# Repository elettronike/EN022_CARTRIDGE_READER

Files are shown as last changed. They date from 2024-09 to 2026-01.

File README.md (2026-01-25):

# EN022 CARTRIDGE READER

## Supported Console Cartridge.

## (GB) Game Boy
[Game Boy related schematics](https://github.com/Gekkio/gb-schematics?tab=readme-ov-file) 

[Jeff Frohwein's GameBoy Tech Page](http://www.devrs.com/gb/files/hardware.html)
Cartridge Voltage 3.3V
System Clock: 4MHz

## (GBA) Gameboy Advanced

[retrosix](https://www.retrosix.wiki/schematics-game-boy-advance) Here are the original scanned schematics of the Game Boy Advance console.

## (NES)

[schematics](https://github.com/schenkzoola/NES)
[nesdev cartridge connector](https://www.nesdev.org/wiki/Cartridge_connector)

Cartridge Voltage 3.3V

## (SNES)

### SNES CIC

## (N64) Nintendo 64

## (MS) Master System

## PCE/TG16	

## Wonderswan	

## CASIO  Loopy

## References

# License

All the schematics in this repository are licensed very liberally under CC BY 4.0, so you can copy, distribute, modify, or even sell them commercially if you want. There's just one requirement: attribution

Basically it just means this: don't remove the original creator's name, or at least somehow acknowledge them. [Here's the full description about it in CC BY 4.0(https://creativecommons.org/licenses/by/4.0/#deed-conditions)]

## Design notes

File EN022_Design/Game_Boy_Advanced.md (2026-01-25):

# Game Boy Advanced

## Pinout

32pin cartridge slot.

The cartridge bus may be used for both CGB and GBA game paks. In GBA mode, it is used as follows:

| Pin | Name | Dir | Description |
| ----- | --- | --- | :--- |
| 1 | VDD35  | ⟸  | Power Supply (3.3VDC/5VDC) |
| 2 | PHI | ⟸  | System Clock (selectable none, 4.19MHz, 8.38MHz, 16.78MHz) |
| 3 | /WR | ⟸  | Write Select |
| 4 | /RD | ⟸  | Read Select |
| 5 | /CS | ⟸  | ROM Chip Select |
| 6-21  | AD0-15 | ⟺  | lower 16bit Address and/or 16bit ROM-data (see below) |
| 22-29 | A16-23 | ⟺  | upper 8bit ROM-Address or 8bit SRAM-data (see below) |
| 30 | /CS2 | ⟸  | SRAM Chip Select |
| 31 | /REQ | ⟹  | Interrupt request (/IREQ) or DMA request (/DREQ) |
| 32 | GND | --  | Ground 0V |

*Note: Direction is cartridge relative Game Boy.*

### GBA Game Pak SRAM

A 16bit address is outputed through AD0-AD15, then 8bit of data are transferred through A16-A23.

### GBA Game Pak ROM

24bit address is output through AD0-AD15 and A16-A23, then 16bit of data are transferred through AD0-AD15. The 24bit address is formed from the actual 25bit memory address (byte-steps), divided by two (halfword-steps).

### Game Pak 8-bit

In 8-bit mode 5V is used. [GBA](http://hardwarebook.info/GBA "GBA") & [GBA SP](http://hardwarebook.info/GBA_SP "GBA SP") have a mechanical switch which the card pushes to select between 3V or 5V.

In 8bit mode, the cartridge bus works much like for GBA SRAM, however, the 8bit /CS signal is expected at Pin 5, while GBA SRAM /CS2 at Pin 30 is interpreted as /RESET signal by the 8bit MBC chip (if any). In practice, this appears to result in 00h being received as data when attempting to read-out 8bit cartridges from inside of GBA mode.

## Compatibility

Compatibility for differents Game Pak type:

| | Original | Dual Mode | Color only | Advanced only |
| --- | --- | --- | --- | --- |
| [Game Boy](http://hardwarebook.info/GB "GB") | OK | OK | - | - |
| Game Boy Pocket | OK | OK | - | - |
| [Game Boy Color](http://hardwarebook.info/GBC "GBC") | OK | OK | OK | - |
| [Game Boy Advance](http://hardwarebook.info/GBA "GBA") / [Game Boy Advance SP](http://hardwarebook.info/GBA_SP "GBA SP") | OK | OK | OK | OK |
| Nintendo[GameCube](http://hardwarebook.info/GameCube "GameCube") Game Boy Player | OK | OK | OK | OK |
| [Game Boy Micro](http://hardwarebook.info/GBM "GBM") | - | - | - | OK |
| [Nintendo DS](http://hardwarebook.info/NDS "NDS") / [Nintendo DS Lite](http://hardwarebook.info/NDSL "NDSL") | - | - | - | OK |

## Game PAK ROM

16-bit with variable size: This is the place where the cartridge ROM is accessed.
While it may provide one of the slowest rates, it’s also mirrored in the memory map to manage different access speeds.
Additionally, Nintendo fitted a Prefetch Buffer that interfaces the cartridge to alleviate excessive stalling.
This component independently caches continuous addresses when the CPU is not accessing the cartridge, it can hold up to eight 16-bit words.
In practice, however, the CPU will rarely let the Prefetch Buffer do its job.
Since by default it will keep fetching instructions from the cartridge to continue execution [20] (hence why IWRAM and EWRAM are so critical).

## Game PAK RAM

8-bit with variable size: This is the place where the cartridge RAM (SRAM or Flash Memory) is accessed.
This is strictly an 8-bit bus (the CPU will see ‘garbage’ in the unused bits) and for this reason, Nintendo states that it can only be operated through their libraries.

## Game pack Detection Switch

## References

[Game Boy Advance Architecture](https://www.copetti.org/writings/consoles/game-boy-advance/)
[Game Pak](http://hardwarebook.info/Game_Pak)
[GBATEK](https://problemkaputt.de/gbatek.htm#gbatechnicaldata) Gameboy Advance / Nintendo DS / DSi / 3DS - Technical Info - Extracted from no$gba version 3.05
[GBxCartRead ](https://www.insidegadgets.com/2016/12/06/gbxcartread-part-1-design-and-testing-gameboy-carts/)– Part 1: Design and Testing Gameboy Carts

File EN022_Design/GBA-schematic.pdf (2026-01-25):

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

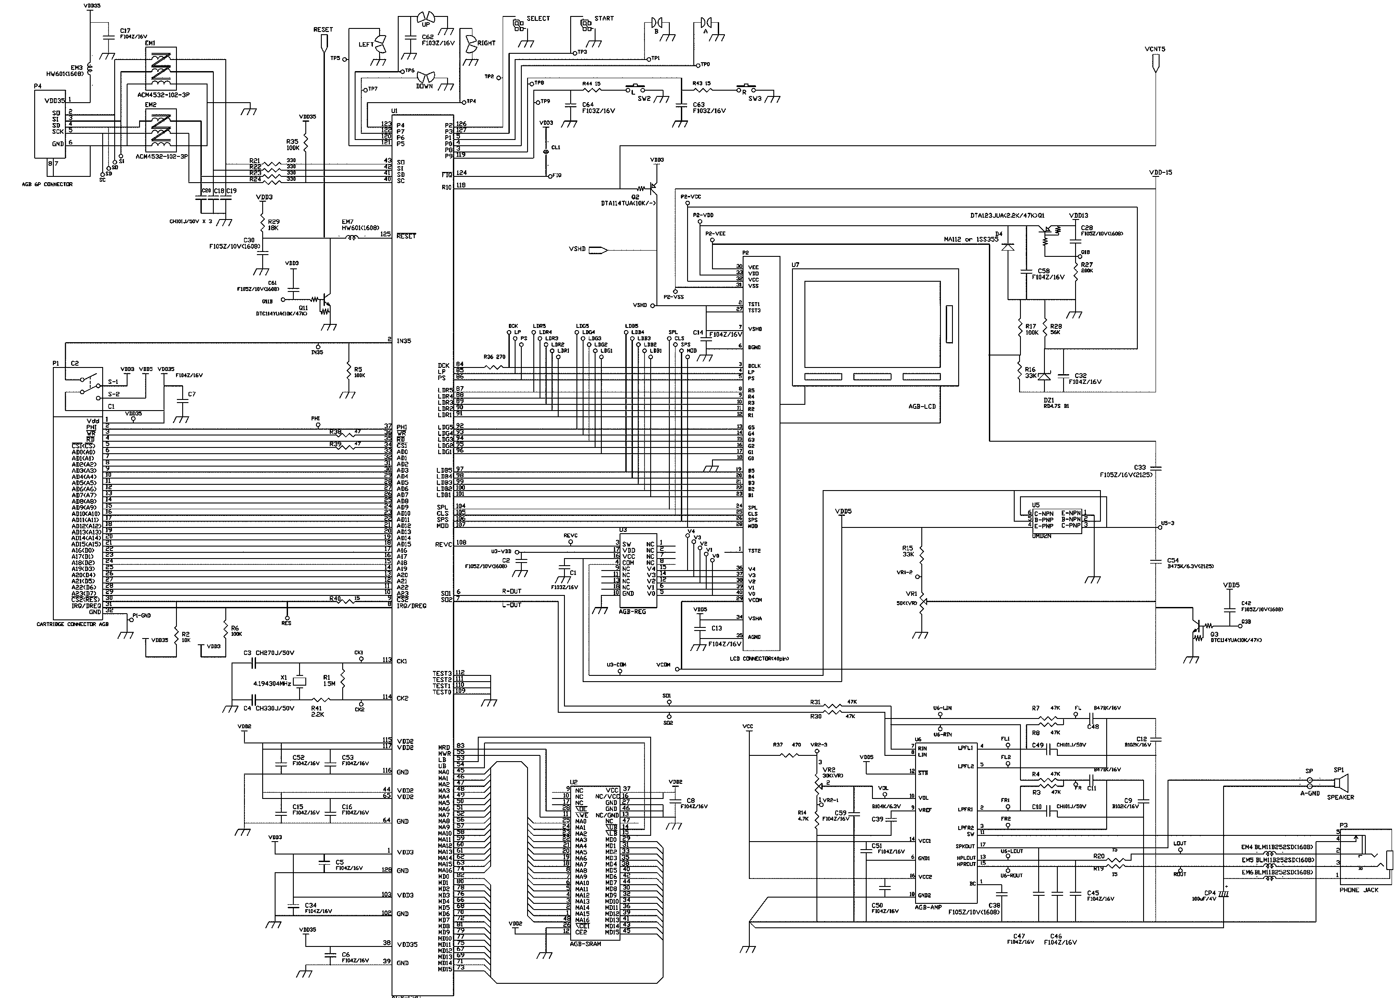
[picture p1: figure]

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

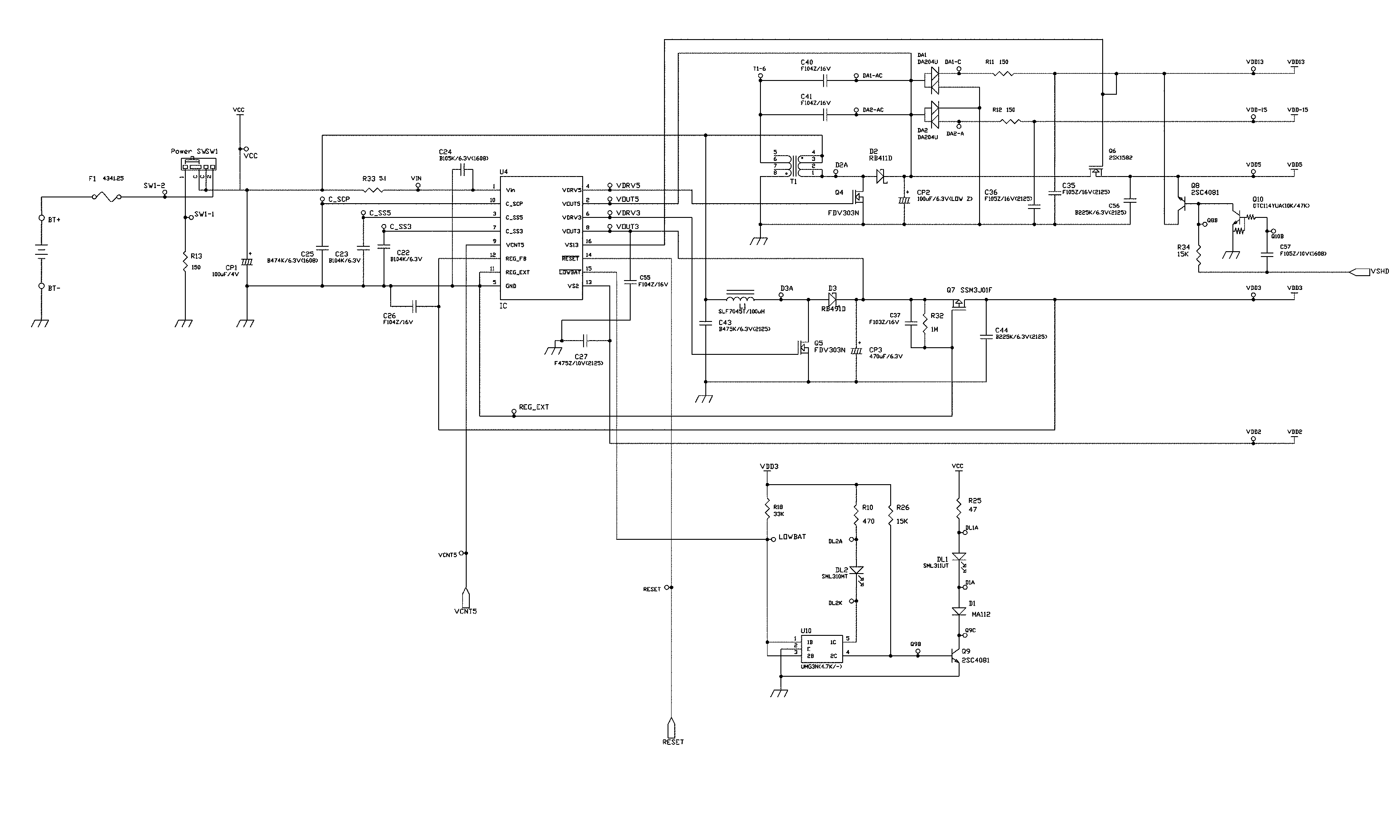
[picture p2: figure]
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

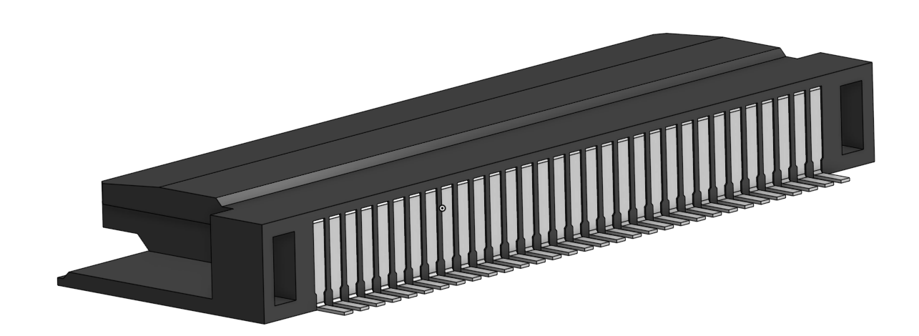
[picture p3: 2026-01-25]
gbcc2.png

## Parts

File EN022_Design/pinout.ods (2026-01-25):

Arduino | Alt. Arduino | ATMega2560 | CH32V307VCT6 | FUNCTION | Game Boy | GBA | NES | SNES | snesCIC | N64 ROM | N64 Controller | N64 EEP | Master System | Megadrive | PCE/TG16 | Wonderswan | CASIO Loopy | LED | SD Card | OLED | LCD | Button | Rotary Encoder | Neopixel | 16bit Flash | 8bit Flash | 16bit Flash in 8bit Mode | 27C322 Eprom
A0 | D54 | PF0 |  |  | A0 | AD0 | M2 | A0 |  | AD0 |  |  | A0 | A1 | A0 | A-1 | D10 |  |  |  |  |  |  |  | A0 | A0 | D15 | A0
A1 | D55 | PF1 |  |  | A1 | AD1 | PRG_CE | A1 |  | AD1 |  |  | A1 | A2 | A1 | A0 | D8 |  |  |  |  |  |  |  | A1 | A1 | A0 | A1
A2 | D56 | PF2 |  |  | A2 | AD2 | CHR_WR | A2 |  | AD2 |  |  | A2 | A3 | A2 | A1 | D6 |  |  |  |  |  |  |  | A2 | A2 | A1 | A2
A3 | D57 | PF3 |  |  | A3 | AD3 | CIRAM_CE | A3 |  | AD3 |  |  | A3 | A4 | A3 | A2 | D4 |  |  |  |  |  |  |  | A3 | A3 | A2 | A3
A4 | D58 | PF4 |  |  | A4 | AD4 | CHR_/A13 | A4 |  | AD4 |  |  | A4 | A5 | A4 | A3 | D14 |  |  |  |  |  |  |  | A4 | A4 | A3 | A4
A5 | D59 | PF5 |  |  | A5 | AD5 | CHR_RD | A5 |  | AD5 |  |  | A5 | A6 | A5 | A4 | D3 |  |  |  |  |  |  |  | A5 | A5 | A4 | A5
A6 | D60 | PF6 |  |  | A6 | AD6 | IRQ | A6 |  | AD6 |  |  | A6 | A7 | A6 | A5 | D2 |  |  |  |  |  |  |  | A6 | A6 | A5 | A6
A7 | D61 | PF7 |  |  | A7 | AD7 | PRG_RW | A7 |  | AD7 |  |  | A7 | A8 | A7 | A6 | RESET |  |  |  |  |  |  |  | A7 | A7 | A6 | A7
A8 | D62 | PK0 |  |  | A8 | AD8 | D0 | A8 |  | AD8 |  |  | A8 | A9 | A8 | A7 | D0 |  |  |  |  |  |  |  | A8 | A8 | A7 | A8
A9 | D63 | PK1 |  |  | A9 | AD9 | D1 | A9 |  | AD9 |  |  | A9 | A10 | A9 | A8 | A0 |  |  |  |  |  |  |  | A9 | A9 | A8 | A9
A10 | D64 | PK2 |  |  | A10 | AD10 | D2 | A10 |  | AD10 |  |  | A10 | A11 | A10 | A9 | A1 |  |  |  |  |  |  |  | A10 | A10 | A9 | A10
A11 | D65 | PK3 |  |  | A11 | AD11 | D3 | A11 |  | AD11 |  |  | A11 | A12 | A11 | A10 | A21 |  |  |  |  |  |  |  | A11 | A11 | A10 | A11
A12 | D66 | PK4 |  |  | A12 | AD12 | D4 | A12 |  | AD12 |  |  | A12 | A13 | A12 | A11 | A3 |  |  |  |  |  |  |  | A12 | A12 | A11 | A12
A13 | D67 | PK5 |  |  | A13 | AD13 | D5 | A13 |  | AD13 |  |  | A13 | A14 | A13 | A12 | A20 |  |  |  |  |  |  |  | A13 | A13 | A12 | A13
A14 | D68 | PK6 |  |  | A14 | AD14 | D6 | A14 |  | AD14 |  |  | A14 | A15 | A14 | A13 | A15 |  |  |  |  |  |  |  | A14 | A14 | A13 | A14
A15 | D69 | PK7 |  |  | A15 | AD15 | D7 | A15 |  | AD15 |  |  |  | A16 | A15 | A14 | A13 |  |  |  |  |  |  |  | A15 | A15 | A14 | A15
D0 | RX0 | PE0
D1 | TX0 | PE1 |  |  |  |  |  |  |  |  |  |  |  |  |  |  |  | build-in (LCD blink)
D2 | PWM | PE4 |  |  |  |  |  | WRAM |  |  |  |  |  | (YS) |  | IO | D11
D3 | PWM | PE5 |  |  |  |  |  | REFRESH |  |  |  |  |  | CAS2 |  | CLK | D9
D4 | PWM | PG5 |  |  |  |  |  | EXPAND |  |  |  |  |  | ASEL |  | Int | D15
D5 | PWM | PE3 |  |  |  |  |  |  |  |  |  |  |  | EDCLK
D6 | PWM | PH3 |  |  | CS | CS_ROM |  | CS |  |  |  |  | A15/M0-7 | CS | OE | CART | RAMWE |  |  |  |  |  |  |  | BYTE | OE | OE
D7 (1K Pullup) | PWM | PH4 |  |  | Sound | IRQ |  | IRQ |  |  | DATA | DATA |  | WR HIGH | IRQ2 | MMC | RAMCS2 |  |  |  |  |  |  |  | WE
D8 | PWM | PH5 |  |  | WR | WR |  | WR |  | WR |  |  | WR | WR LOW | WR | WE |  |  |  |  |  |  |  |  | WP | WE | WE | To NPN transistor controlling VPP 12V stepup regulator module
D9 | PWM | PH6 |  |  | RD | RD |  | RD |  | RD |  |  | OE | OE |  | OE |  |  |  |  |  |  |  |  | CE | CE | CE | CE
D10 | PWM | PB4 |  |  |  |  |  |  |  |  |  |  |  |  |  |  |  | Blue (OLED blink) |  |  | Reset
D11 | PWM | PB5 |  |  |  |  |  |  |  |  |  |  |  |  |  |  |  | Green |  |  | DC/A0
D12 | PWM | PB6 |  |  |  |  |  |  |  |  |  |  |  |  |  |  |  | Red |  |  | CS
D13 | PWM | PB7 |  |  |  |  |  |  |  |  |  |  |  |  |  |  |  | build-in (Serial blink) |  |  |  |  |  | Neopixel
D14 | TX3 | PJ1 |  |  |  |  |  | PAWR |  |  |  |  |  | AS |  |  | D12
D15 | RX3 | PJ0 |  |  |  |  |  | PARD |  |  |  |  |  | Time |  |  | D13
D16 | TX2 | PH1 |  | CLOCK | CLK | CLK |  |  |  |  |  |  | CLK | VCLK
D17 | RX2 | PH0 |  | RESET | Reset | CS_RAM |  | Reset |  | Reset |  | Reset | Reset | (MRES),VRES | RST | Reset |  |  |  |  |  |  |  |  | Reset | Reset | Reset
D18 | TX1 | PD3 |  |  |  |  |  |  |  |  |  |  |  |  |  |  |  |  |  |  |  |  | ENC1
D19 | RX1 | PD2 |  |  |  |  |  |  |  |  |  |  |  |  |  |  |  |  |  |  |  |  | ENC2
D20 | SDA | PD1 |  |  |  |  |  |  |  |  |  |  |  |  |  |  |  |  |  | SDA
D21 | SCL | PD0 |  |  |  |  |  |  |  |  |  |  |  |  |  |  |  |  |  | SCL
D22 |  | PA0 |  |  |  |  | A8 | PA0 |  |  |  |  |  | D8 |  | D8 | D1 |  |  |  |  |  |  |  | D8 |  |  | D8
D23 |  | PA1 |  |  |  |  | A9 | PA1 |  |  |  |  |  | D9 |  | D9 | A2 |  |  |  |  |  |  |  | D9 |  |  | D9
D24 |  | PA2 |  |  |  |  | A10 | PA2 |  |  |  |  |  | D10 |  | D10 | A4 |  |  |  |  |  |  |  | D10 |  |  | D10
D25 |  | PA3 |  |  |  |  | A11 | PA3 |  |  |  |  |  | D11 |  | D11 | A19 |  |  |  |  |  |  |  | D11 |  |  | D11
D26 |  | PA4 |  |  |  |  | A12 | PA4 |  |  |  |  |  | D12 |  | D12 | A18 |  |  |  |  |  |  |  | D12 |  |  | D12
D27 |  | PA5 |  |  |  |  | A13 | PA5 |  |  |  |  |  | D13 |  | D13 | A16 |  |  |  |  |  |  |  | D13 |  |  | D13
D28 |  | PA6 |  |  |  |  | A14 | PA6 |  |  |  |  |  | D14 |  | D14 | A17 |  |  |  |  |  |  |  | D14 |  |  | D14
D29 |  | PA7 |  |  |  |  |  | PA7 |  |  |  |  |  | D15 |  | D15 | A14 |  |  |  |  |  |  |  | D15 |  |  | D15
D30 |  | PC7 |  |  | D7 | A23 |  | D7 |  |  |  |  | D7 | D7 | D7 | D7 |  |  |  |  |  |  |  |  | D7 | D7 | D7 | D7
D31 |  | PC6 |  |  | D6 | A22 |  | D6 |  |  |  |  | D6 | D6 | D6 | D6 |  |  |  |  |  |  |  |  | D6 | D6 | D6 | D6
D32 |  | PC5 |  |  | D5 | A21 |  | D5 |  |  |  |  | D5 | D5 | D5 | D5 |  |  |  |  |  |  |  |  | D5 | D5 | D5 | D5
D33 |  | PC4 |  |  | D4 | A20 |  | D4 |  |  |  |  | D4 | D4 | D4 | D4 |  |  |  |  |  |  |  |  | D4 | D4 | D4 | D4
D34 |  | PC3 |  |  | D3 | A19 |  | D3 |  |  |  |  | D3 | D3 | D3 | D3 | A12 |  |  |  |  |  |  |  | D3 | D3 | D3 | D3
D35 |  | PC2 |  |  | D2 | A18 | CIRAM_A10 | D2 |  |  |  |  | D2 | D2 | D2 | D2 | A10 |  |  |  |  |  |  |  | D2 | D2 | D2 | D2
D36 |  | PC1 |  |  | D1 | A17 |  | D1 |  | ALE_H |  |  | D1 | D1 | D1 | D1 | A8 |  |  |  |  |  |  |  | D1 | D1 | D1 | D1
D37 |  | PC0 |  |  | D0 | A16 |  | D0 |  | ALE_L |  |  | D0 | D0 | D0 | D0 | A6 |  |  |  |  |  |  |  | D0 | D0 | D0 | D0
D38 |  | PD7 |  |  |  |  |  |  |  |  |  |  |  |  |  |  |  | HW5 status LED |  |  |  | Button1 (10K Pullup)
D39 |  | PG2 |  |  |  |  |  |  |  |  |  |  |  |  |  |  |  |  |  |  |  | Button 2 (10K Pullup) | ENC Button
D40 |  | PG1 |  |  |  |  |  |  | Reset In (Pin 4) |  |  |  |  |  |  |  | D5
D41 |  | PG0 |  |  |  |  |  |  | Reset Out Host (Pin 3) |  |  |  |  |  |  |  | D7
D42 |  | PL7 |  |  |  |  | A7 | A23 |  |  |  |  |  |  | Card Detect |  | CE
D43 |  | PL6 |  |  |  |  | A6 | A22 |  |  |  |  |  | A23 | Audio In |  | OE |  |  |  |  |  |  |  |  |  | A21
D44 | PWM | PL5 |  |  |  |  | A5 | A21 |  |  |  |  |  | A22 | HSM |  |  |  |  |  |  |  |  |  | A21 | A21 | A20
D45 | PWM | PL4 |  |  |  |  | A4 | A20 |  |  |  |  |  | A21 | CE |  |  |  |  |  |  |  |  |  | A20 | A20 | A19 | A20
D46 | PWM | PL3 |  |  |  |  | A3 | A19 |  |  |  |  |  | A20 | A19 | A18 | A11 |  |  |  |  |  |  |  | A19 | A19 | A18 | A19
D47 |  | PL2 |  |  |  |  | A2 | A18 |  |  |  |  |  | A19 | A18 | A17 | A9 |  |  |  |  |  |  |  | A18 | A18 | A17 | A18
D48 |  | PL1 |  |  |  |  | A1 | A17 |  |  |  |  | CE | A18 | A17 | A16 | A7 |  |  |  |  |  |  |  | A17 | A17 | A16 | A17
D49 |  | PL0 |  |  |  |  | A0 | A16 |  |  |  |  |  | A17 | A16 | A15 | A5 |  |  |  |  |  |  |  | A16 | A16 | A15 | A16
D50 | MISO | PB3 |  | MISO |  |  |  |  |  |  |  |  |  |  |  |  |  |  | MISO
D51 | MOSI | PB2 |  | MOSI |  |  |  |  |  |  |  |  |  |  |  |  |  |  | MOSI |  | MOSI
D52 | SCK | PB1 |  | SCK |  |  |  |  |  |  |  |  |  |  |  |  |  |  | SCK |  | SCK
D53 | SS | PB0 |  | SS |  |  |  |  |  |  |  |  |  |  |  |  |  |  | SS
CLK0 |  |  |  |  |  |  |  | CLK
CLK1 |  |  |  |  |  |  |  | CPUCLK |  |  |  | EEP CLK
CLK2 |  |  |  |  |  |  |  | CICCLK | CLK (Pin 2)
 |  |  |  |  |  |  |  | Reset In | Reset Out Slave (Pin 5)
 |  |  |  |  |  |  |  | CIC1 | CIC1 (Pin 6)
 |  |  |  |  |  |  |  | CIC0 | CIC0 (Pin 7)
GND |  |  |  |  |  |  |  |  |  |  |  |  |  |  |  |  |  |  |  |  |  |  |  |  |  |  | BYTE

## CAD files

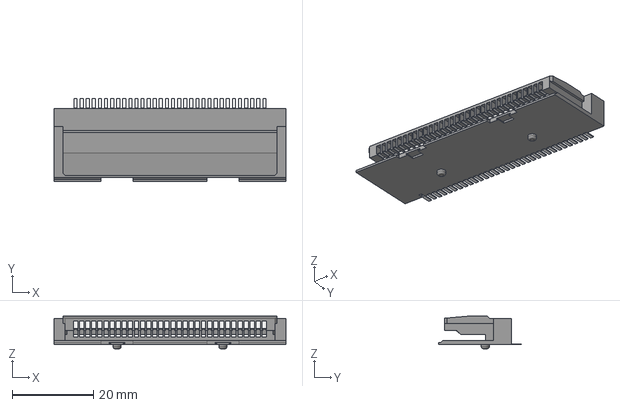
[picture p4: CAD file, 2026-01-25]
footprints/GBA_CartConnector.step
57.0 x 20.4 x 8.00 mm
Pin x 32
Cart_Connector

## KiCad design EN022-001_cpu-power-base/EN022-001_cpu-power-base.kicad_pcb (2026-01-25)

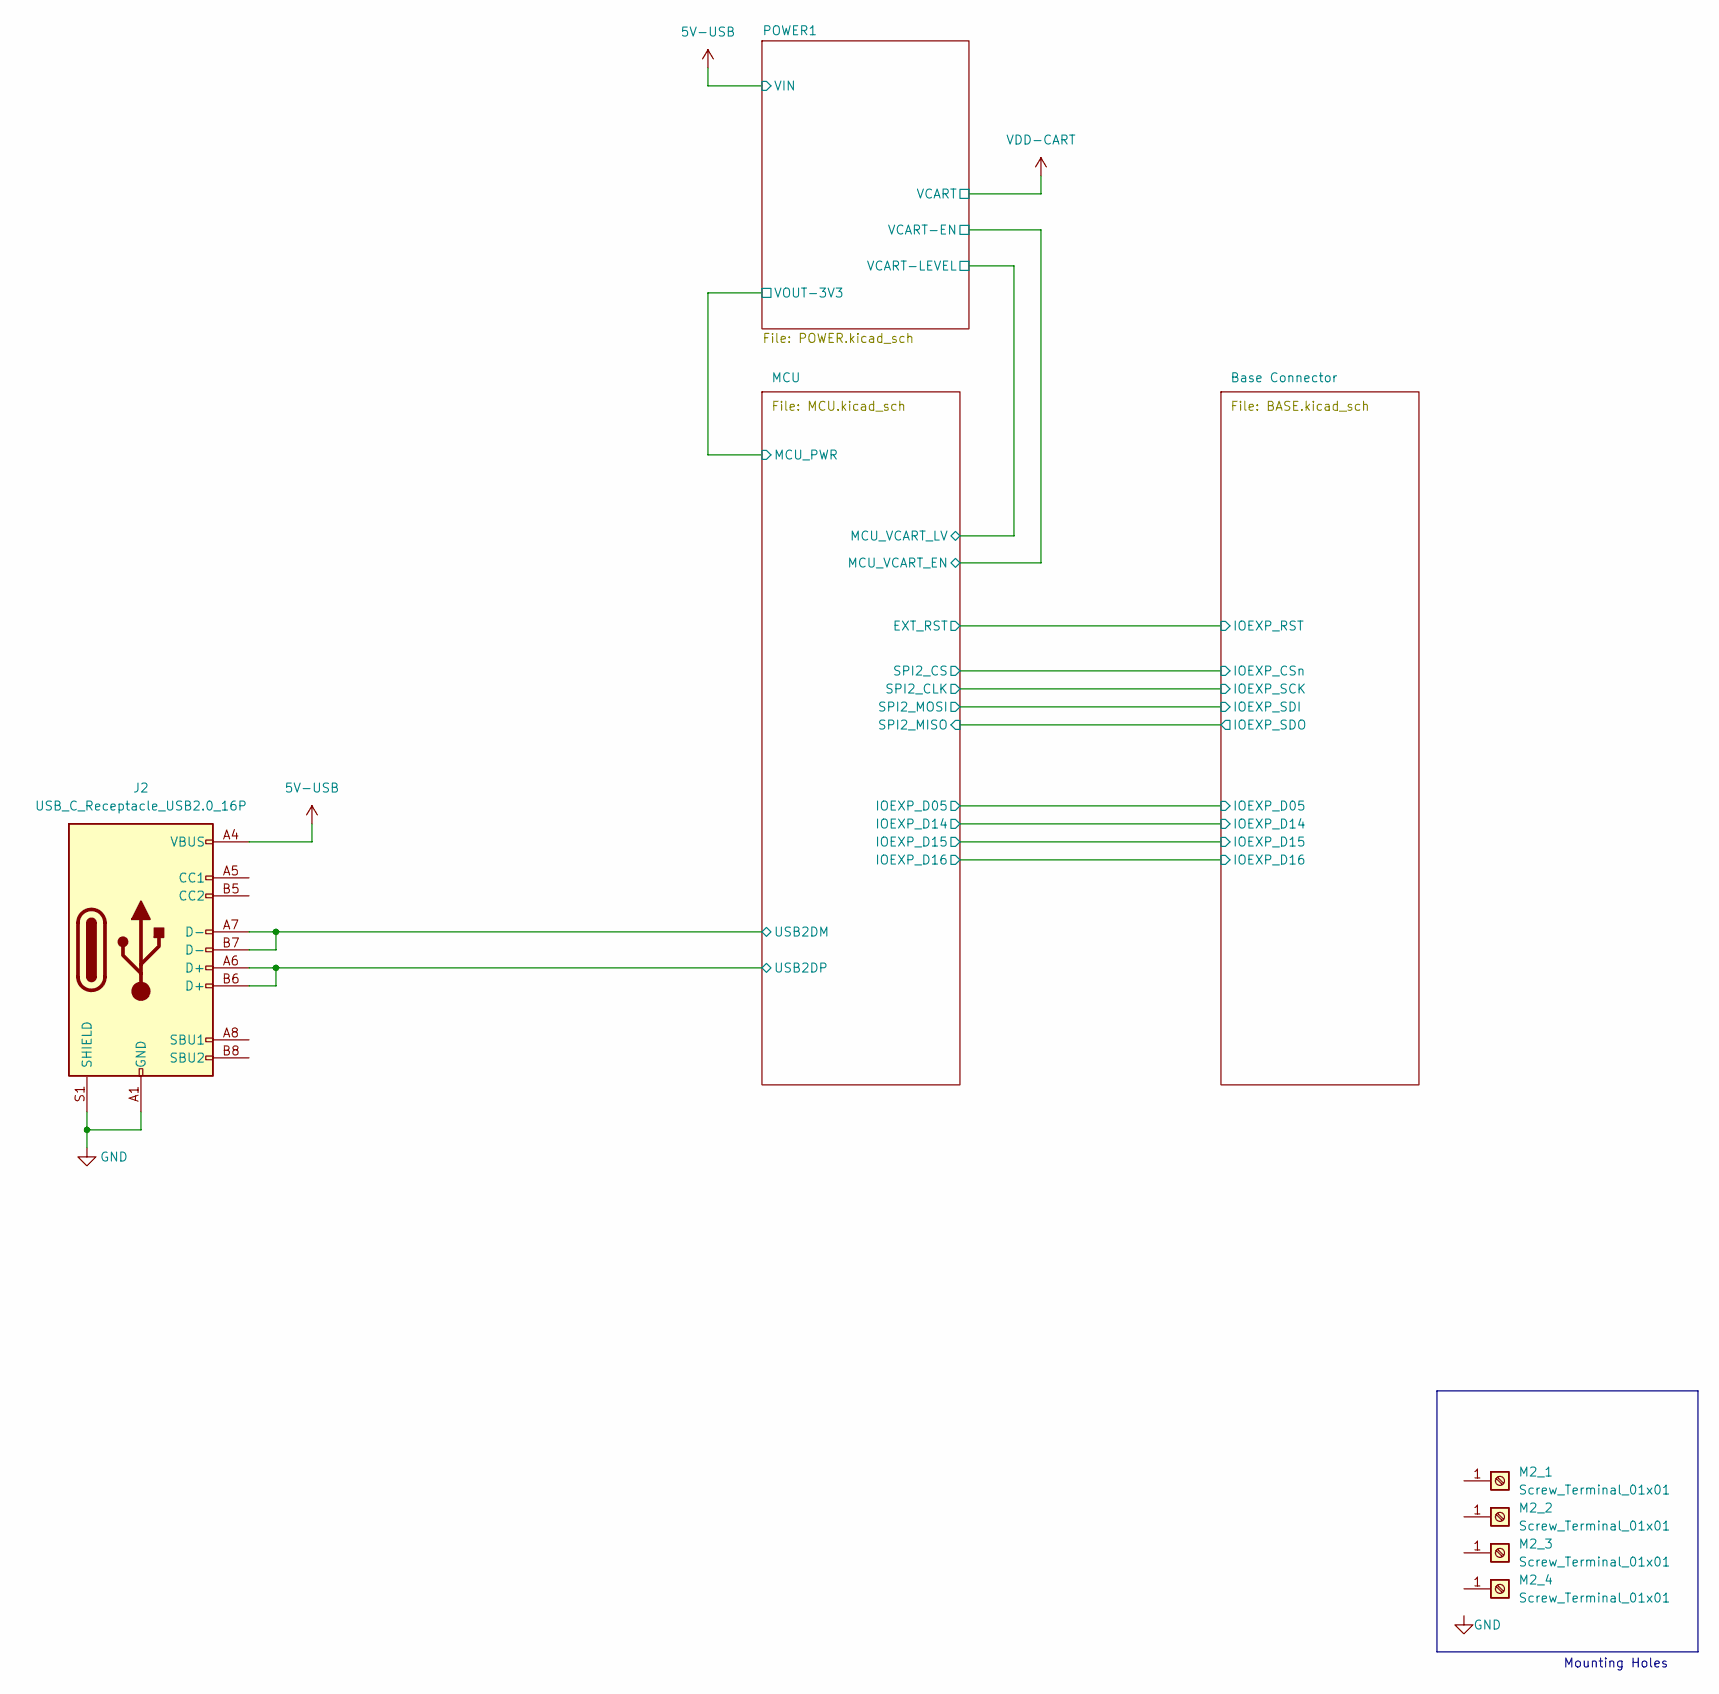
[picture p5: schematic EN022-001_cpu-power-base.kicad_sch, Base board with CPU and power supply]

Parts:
J2: USB_C_Receptacle_USB2.0_16P; USB_C_Receptacle_GCT_USB4105-xx-A_16P_TopMnt_Horizontal
M2_1, M2_2, M2_3, M2_4: Screw_Terminal_01x01

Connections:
5V-USB: J2.A4 (VBUS), J2.A9 (VBUS), J2.B4 (VBUS), J2.B9 (VBUS); also elsewhere on the board
/MCU/USB2DM: J2.A7 (D-), J2.B7 (D-); also elsewhere on the board
/MCU/USB2DP: J2.A6 (D+), J2.B6 (D+); also elsewhere on the board
GND: J2.A1 (GND), J2.A12 (GND), J2.B1 (GND), J2.B12 (GND), J2.S1 (SHIELD); also elsewhere on the board

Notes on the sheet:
Mounting Holes

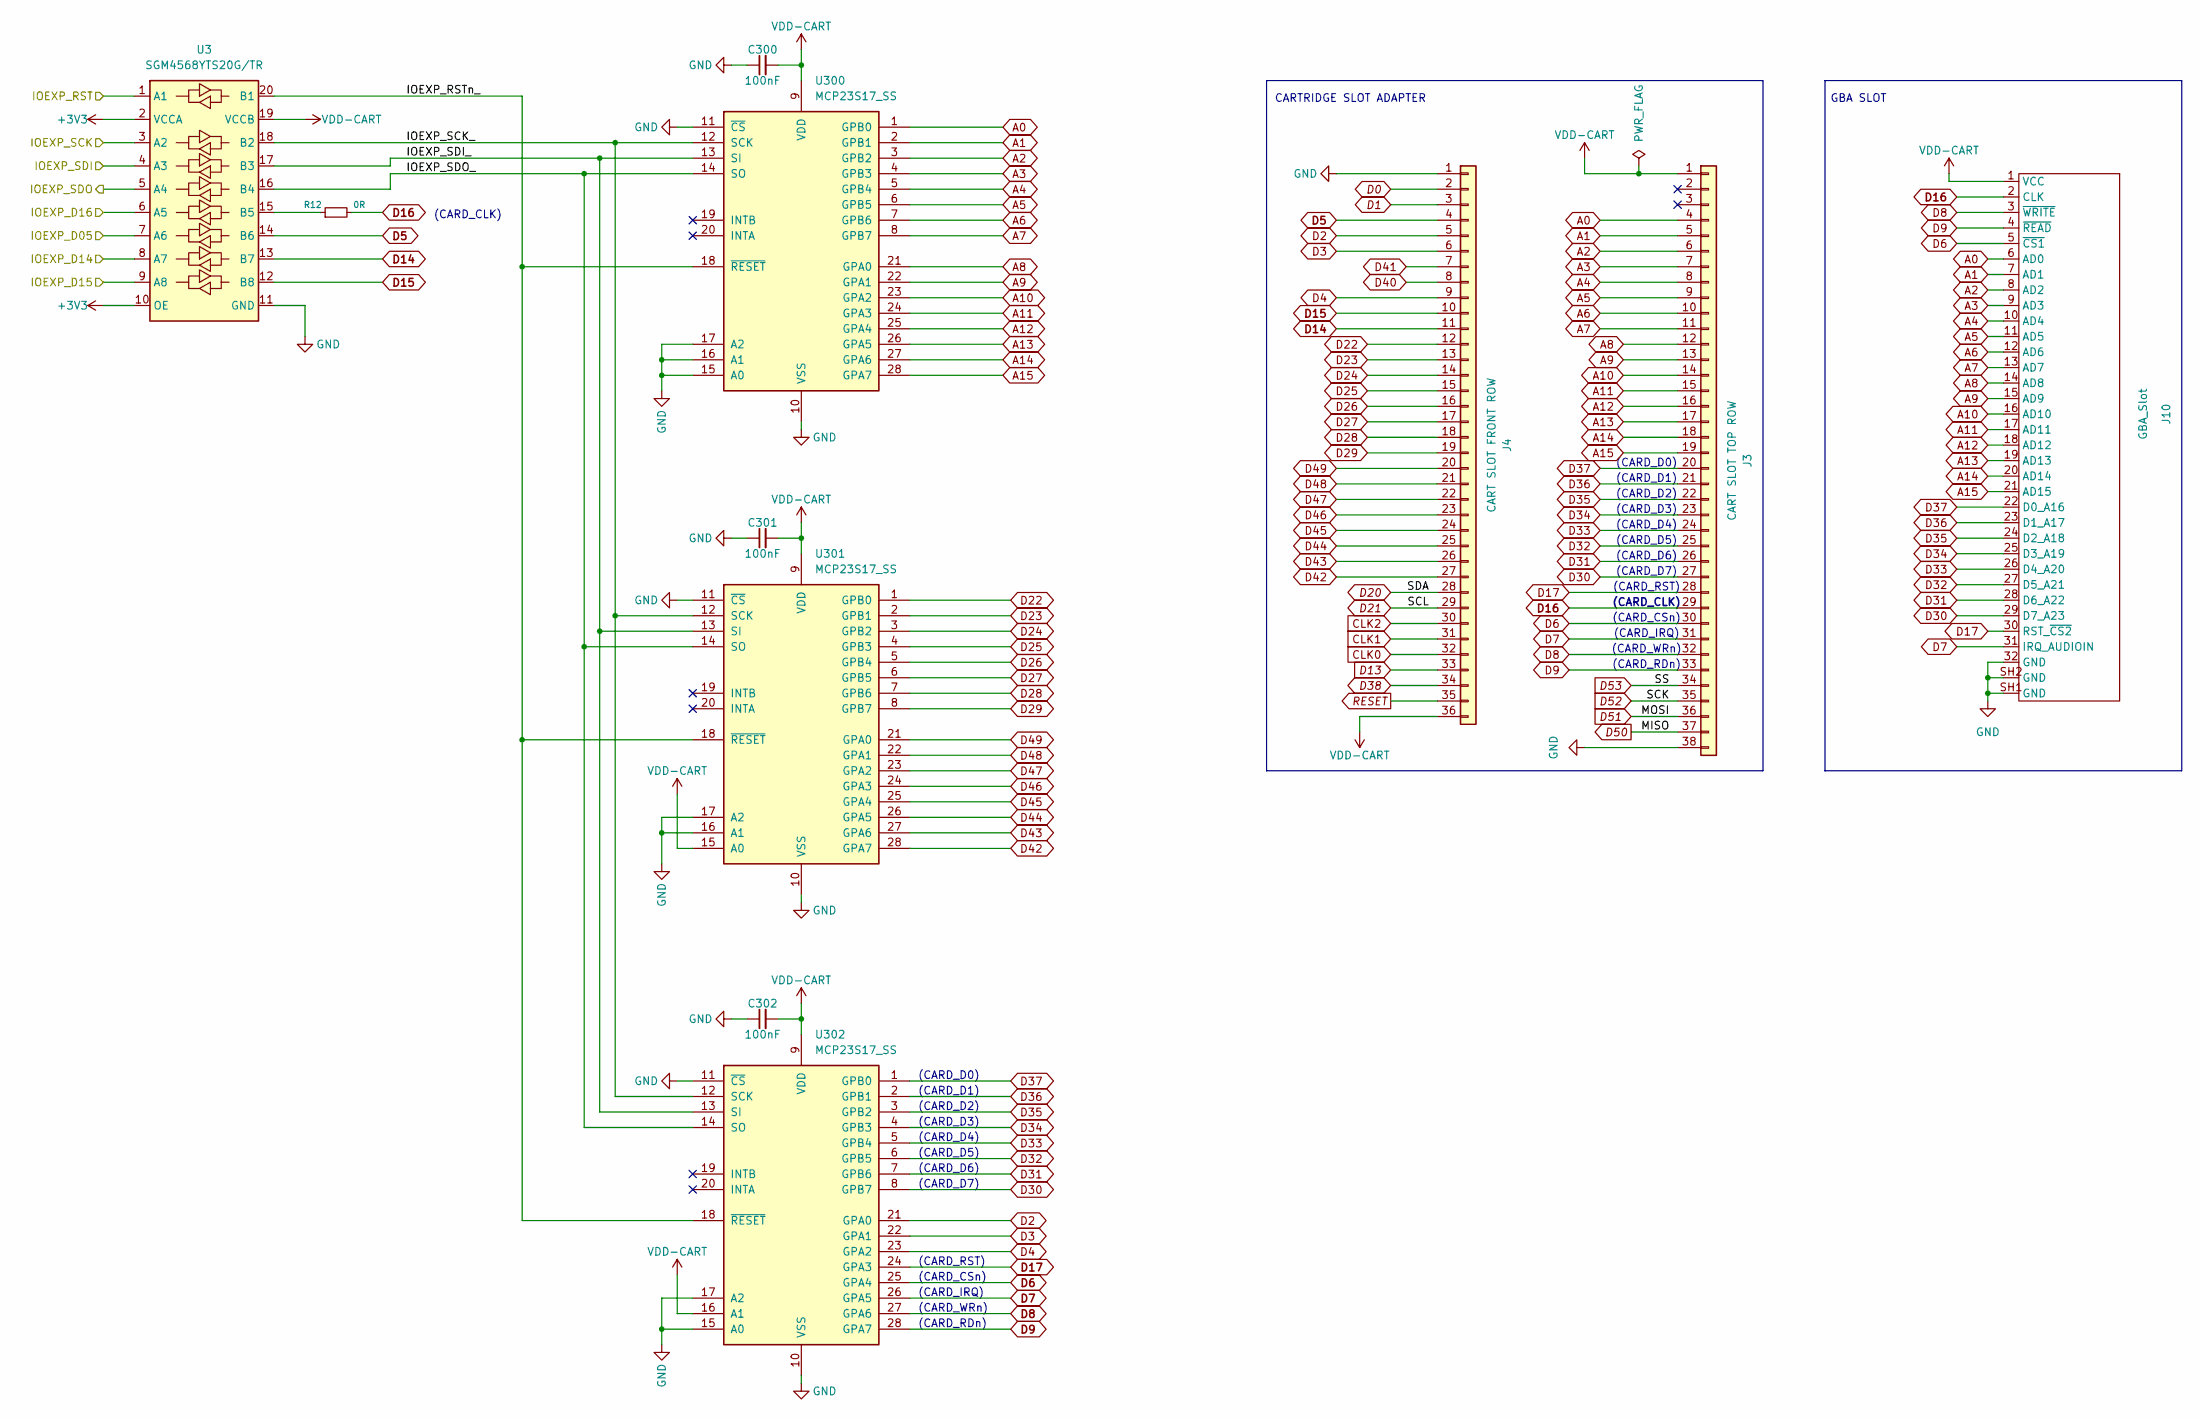
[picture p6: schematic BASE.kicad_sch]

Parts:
C300, C301, C302: 100nF; C_0805_2012Metric_Pad1.18x1.45mm_HandSolder
J3: CART SLOT TOP ROW; Cartridge_Port_Adapter-Back
J4: CART SLOT FRONT ROW; Cartridge_Port_Adapter-Front
J10: GBA_Slot
R12: 0R; R_0805_2012Metric_Pad1.20x1.40mm_HandSolder
U3: SGM4568YTS20G/TR; TSSOP-20_4.4x6.5mm_P0.65mm
U300, U301, U302: MCP23S17_SS; SSOP-28_5.3x10.2mm_P0.65mm

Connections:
+3V3: U3.2 (VCCA), U3.10 (OE); also elsewhere on the board
/Base Connector/IOEXP_D05: U3.7 (A6); also elsewhere on the board
/Base Connector/IOEXP_D14: U3.8 (A7); also elsewhere on the board
/Base Connector/IOEXP_D15: U3.9 (A8); also elsewhere on the board
/Base Connector/IOEXP_D16: U3.6 (A5); also elsewhere on the board
/Base Connector/IOEXP_RST: U3.1 (A1); also elsewhere on the board
/Base Connector/IOEXP_RSTn_: U3.20 (B1), U300.18 (~RESET), U301.18 (~RESET), U302.18 (~RESET)
/Base Connector/IOEXP_SCK: U3.3 (A2); also elsewhere on the board
/Base Connector/IOEXP_SCK_: U3.18 (B2), U300.12 (SCK), U301.12 (SCK), U302.12 (SCK)
/Base Connector/IOEXP_SDI: U3.4 (A3); also elsewhere on the board
/Base Connector/IOEXP_SDI_: U3.17 (B3), U300.13 (SI), U301.13 (SI), U302.13 (SI)
/Base Connector/IOEXP_SDO: U3.5 (A4); also elsewhere on the board
/Base Connector/IOEXP_SDO_: U3.16 (B4), U300.14 (SO), U301.14 (SO), U302.14 (SO)
A0: J3.4, J10.6 (AD0), U300.1 (GPB0)
A1: J3.5, J10.7 (AD1), U300.2 (GPB1)
A2: J3.6, J10.8 (AD2), U300.3 (GPB2)
A3: J3.7, J10.9 (AD3), U300.4 (GPB3)
A4: J3.8, J10.10 (AD4), U300.5 (GPB4)
A5: J3.9, J10.11 (AD5), U300.6 (GPB5)
A6: J3.10, J10.12 (AD6), U300.7 (GPB6)
A7: J3.11, J10.13 (AD7), U300.8 (GPB7)
A8: J3.12, J10.14 (AD8), U300.21 (GPA0)
A9: J3.13, J10.15 (AD9), U300.22 (GPA1)
A10: J3.14, J10.16 (AD10), U300.23 (GPA2)
A11: J3.15, J10.17 (AD11), U300.24 (GPA3)
A12: J3.16, J10.18 (AD12), U300.25 (GPA4)
A13: J3.17, J10.19 (AD13), U300.26 (GPA5)
A14: J3.18, J10.20 (AD14), U300.27 (GPA6)
A15: J3.19, J10.21 (AD15), U300.28 (GPA7)
CLK0: J4.32
CLK1: J4.31
CLK2: J4.30
D0: J4.2
D1: J4.3
D2: J4.5, U302.21 (GPA0)
D3: J4.6, U302.22 (GPA1)
D4: J4.9, U302.23 (GPA2)
D5: J4.4, U3.14 (B6)
D6: J3.30, J10.5 (~CS1), U302.25 (GPA4)
D7: J3.31, J10.31 (IRQ_AUDIOIN), U302.26 (GPA5)
D8: J3.32, J10.3 (~WRITE), U302.27 (GPA6)
D9: J3.33, J10.4 (~READ), U302.28 (GPA7)
D13: J4.33
D14: J4.11, U3.13 (B7)
D15: J4.10, U3.12 (B8)
D16: J3.29, J10.2 (CLK), R12.2
D17: J3.28, J10.30 (RST_~CS2), U302.24 (GPA3)
D20: J4.28
D21: J4.29
D22: J4.12, U301.1 (GPB0)
D23: J4.13, U301.2 (GPB1)
D24: J4.14, U301.3 (GPB2)
D25: J4.15, U301.4 (GPB3)
D26: J4.16, U301.5 (GPB4)
D27: J4.17, U301.6 (GPB5)
D28: J4.18, U301.7 (GPB6)
D29: J4.19, U301.8 (GPB7)
D30: J3.27, J10.29 (D7_A23), U302.8 (GPB7)
D31: J3.26, J10.28 (D6_A22), U302.7 (GPB6)
D32: J3.25, J10.27 (D5_A21), U302.6 (GPB5)
D33: J3.24, J10.26 (D4_A20), U302.5 (GPB4)
D34: J3.23, J10.25 (D3_A19), U302.4 (GPB3)
D35: J3.22, J10.24 (D2_A18), U302.3 (GPB2)
D36: J3.21, J10.23 (D1_A17), U302.2 (GPB1)
D37: J3.20, J10.22 (D0_A16), U302.1 (GPB0)
D38: J4.34
D40: J4.8
D41: J4.7
D42: J4.27, U301.28 (GPA7)
D43: J4.26, U301.27 (GPA6)
D44: J4.25, U301.26 (GPA5)
D45: J4.24, U301.25 (GPA4)
D46: J4.23, U301.24 (GPA3)
D47: J4.22, U301.23 (GPA2)
D48: J4.21, U301.22 (GPA1)
D49: J4.20, U301.21 (GPA0)
D50: J3.37
D51: J3.36
D52: J3.35
D53: J3.34
GND: C300.1, C301.1, C302.1, J3.38, J4.1, J10.32 (GND), J10.SH1 (GND), J10.SH2 (GND), U3.11 (GND), U300.10 (VSS), U300.11 (~CS), U300.15 (A0), U300.16 (A1), U300.17 (A2), U301.10 (VSS), U301.11 (~CS), U301.16 (A1), U301.17 (A2), U302.10 (VSS), U302.11 (~CS), U302.15 (A0), U302.17 (A2); also elsewhere on the board
unnamed: R12.1, U3.15 (B5)
RESET: J4.35
VDD-CART: C300.2, C301.2, C302.2, J3.1, J4.36, J10.1 (VCC), U3.19 (VCCB), U300.9 (VDD), U301.9 (VDD), U301.15 (A0), U302.9 (VDD), U302.16 (A1); also elsewhere on the board

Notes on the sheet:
(CARD_D7)
(CARD_D0)
(CARD_CLK)
(CARD_D6)
GBA SLOT
(CARD_D5)
(CARD_D3)
(CARD_WRn)
(CARD_CSn)
(CARD_D1)
CARTRIDGE SLOT ADAPTER
(CARD_D2)
(CARD_IRQ)
(CARD_D4)
(CARD_RDn)
(CARD_RST)

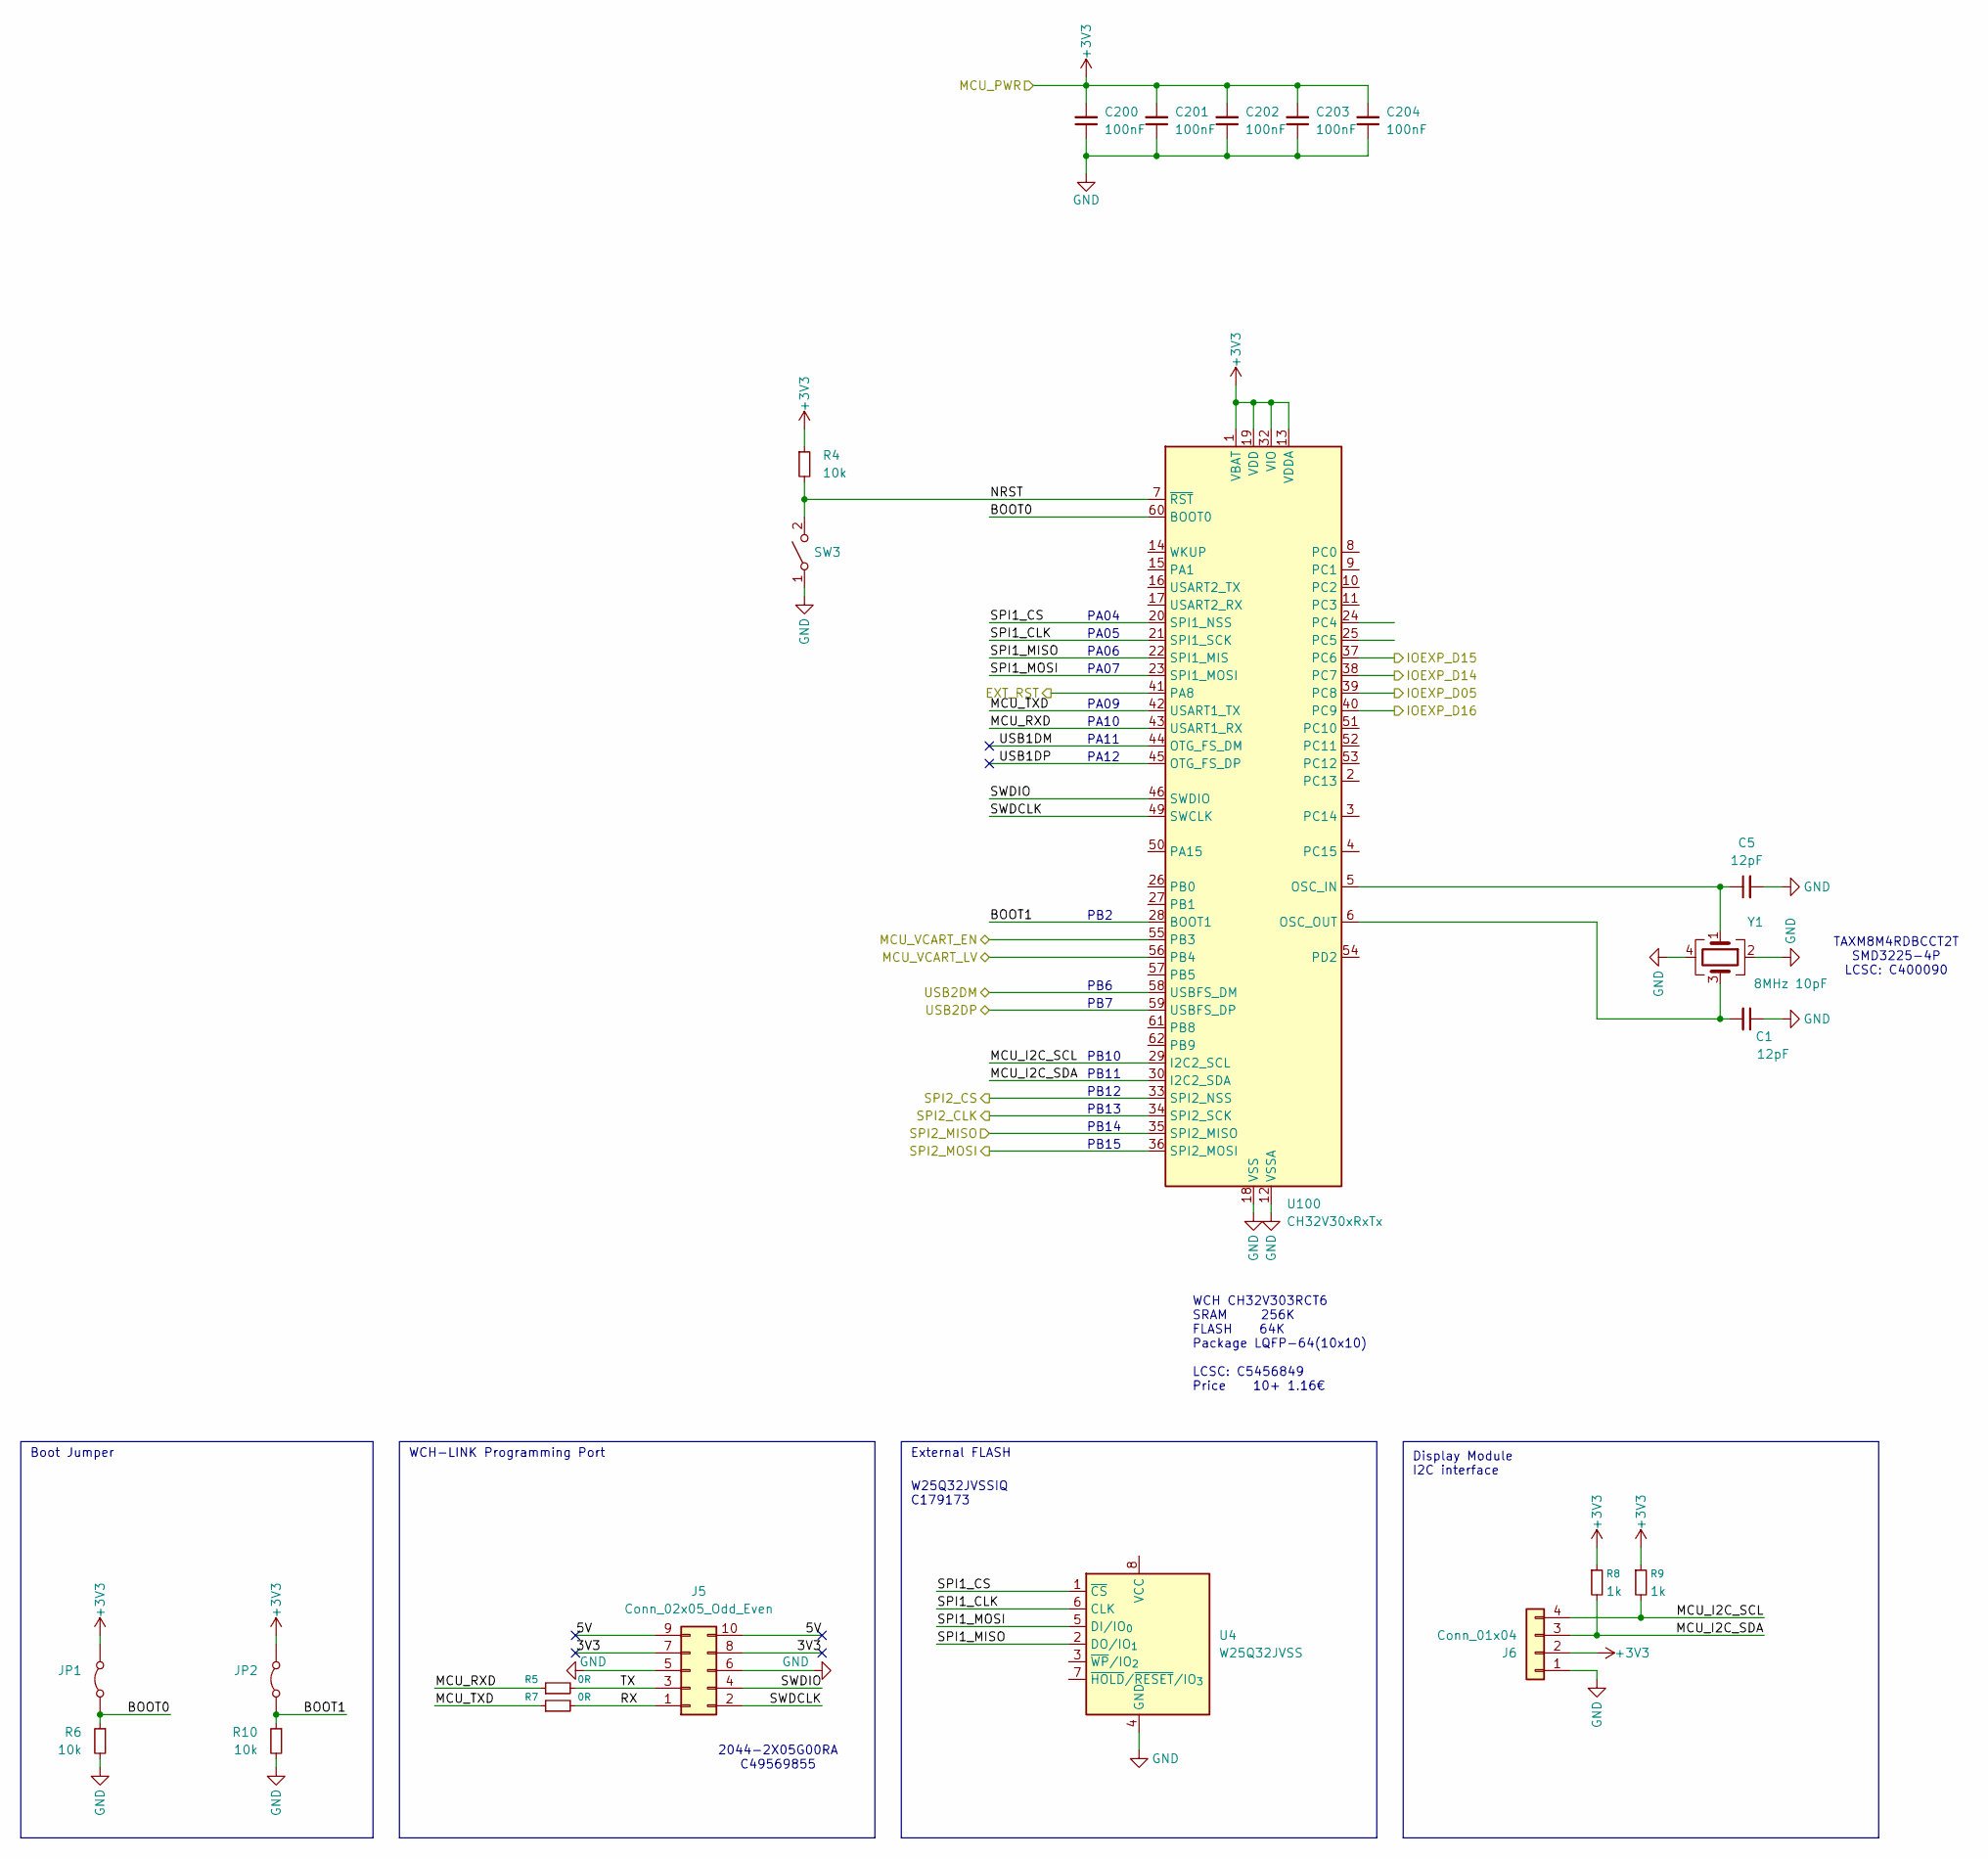
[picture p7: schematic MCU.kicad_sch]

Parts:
C1, C5: 12pF; C_0603_1608Metric_Pad1.08x0.95mm_HandSolder
C200, C201, C202, C203, C204: 100nF; C_0805_2012Metric_Pad1.18x1.45mm_HandSolder
J5: Conn_02x05_Odd_Even; PinSocket_2x05_P2.54mm_Horizontal
J6: Conn_01x04; PinHeader_1x04_P2.54mm_Vertical
JP1, JP2: Jumper_2_Bridged; PinHeader_1x02_P2.54mm_Vertical
R4, R6, R10: 10k; R_0805_2012Metric_Pad1.20x1.40mm_HandSolder
R5, R7: 0R; R_0805_2012Metric_Pad1.20x1.40mm_HandSolder
R8, R9: 1k; R_0805_2012Metric_Pad1.20x1.40mm_HandSolder
SW3: TC-6615-7-260G; SW_Tactile_SPST_Angled_PTS645Vx58-2LFS
U4: W25Q32JVSS; SOIC-8_5.3x5.3mm_P1.27mm
U100: CH32V30xRxTx; LQFP-64_10x10mm_P0.5mm
Y1: 8MHz 10pF; Crystal_SMD_3225-4Pin_3.2x2.5mm_HandSoldering

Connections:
+3V3: C200.2, C201.2, C202.2, C203.2, C204.2, J6.2, JP1.1 (A), JP2.1 (A), R4.1, R8.1, R9.1, U100.1 (VBAT), U100.13 (VDDA), U100.19 (VDD), U100.32 (VIO), U100.48 (VDD), U100.64 (VIO); also elsewhere on the board
/Base Connector/IOEXP_D05: U100.39 (PC8); also elsewhere on the board
/Base Connector/IOEXP_D14: U100.38 (PC7); also elsewhere on the board
/Base Connector/IOEXP_D15: U100.37 (PC6); also elsewhere on the board
/Base Connector/IOEXP_D16: U100.40 (PC9); also elsewhere on the board
/Base Connector/IOEXP_RST: U100.41 (PA8); also elsewhere on the board
/Base Connector/IOEXP_SCK: U100.34 (SPI2_SCK); also elsewhere on the board
/Base Connector/IOEXP_SDI: U100.36 (SPI2_MOSI); also elsewhere on the board
/Base Connector/IOEXP_SDO: U100.35 (SPI2_MISO); also elsewhere on the board
/MCU/3V3: J5.7, J5.8
/MCU/5V: J5.9, J5.10
/MCU/BOOT0: JP1.2 (B), R6.1, U100.60 (BOOT0)
/MCU/BOOT1: JP2.2 (B), R10.1, U100.28 (BOOT1)
/MCU/MCU_I2C_SCL: J6.4, R9.2, U100.29 (I2C2_SCL)
/MCU/MCU_I2C_SDA: J6.3, R8.2, U100.30 (I2C2_SDA)
/MCU/MCU_RXD: R5.1, U100.43 (USART1_RX)
/MCU/MCU_TXD: R7.1, U100.42 (USART1_TX)
/MCU/MCU_VCART_EN: U100.55 (PB3); also elsewhere on the board
/MCU/MCU_VCART_LV: U100.56 (PB4); also elsewhere on the board
/MCU/NRST: R4.2, SW3.2 (B), U100.7 (~RST)
/MCU/RX: J5.1, R7.2
/MCU/SPI1_CLK: U4.6 (CLK), U100.21 (SPI1_SCK)
/MCU/SPI1_CS: U4.1 (~CS), U100.20 (SPI1_NSS)
/MCU/SPI1_MISO: U4.2 (DO/IO_{1}), U100.22 (SPI1_MIS)
/MCU/SPI1_MOSI: U4.5 (DI/IO_{0}), U100.23 (SPI1_MOSI)
/MCU/SPI2_CS: U100.33 (SPI2_NSS)
/MCU/SWDCLK: J5.2, U100.49 (SWCLK)
/MCU/SWDIO: J5.4, U100.46 (SWDIO)
/MCU/TX: J5.3, R5.2
/MCU/USB1DM: U100.44 (OTG_FS_DM)
/MCU/USB1DP: U100.45 (OTG_FS_DP)
/MCU/USB2DM: U100.58 (USBFS_DM); also elsewhere on the board
/MCU/USB2DP: U100.59 (USBFS_DP); also elsewhere on the board
GND: C1.1, C5.2, C200.1, C201.1, C202.1, C203.1, C204.1, J5.5, J5.6, J6.1, R6.2, R10.2, SW3.1 (A), U4.4 (GND), U100.12 (VSSA), U100.18 (VSS), U100.31 (VSS), U100.47 (VSS), U100.63 (VSS), Y1.2, Y1.4; also elsewhere on the board
unnamed: C5.1, U100.5 (OSC_IN), Y1.1
unnamed: C1.2, U100.6 (OSC_OUT), Y1.3

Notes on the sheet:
WCH-LINK Programming Port
PB7
WCH CH32V303RCT6 SRAM 256K FLASH 64K Package LQFP-64(10x10) LCSC: C5456849 Price 10+ 1.16€
W25Q32JVSSIQ C179173
PB11
PB15
TAXM8M4RDBCCT2T SMD3225-4P LCSC: C400090
PB2
PB13
PB14
PB12
PB10
External FLASH
Display Module I2C interface
PA10
PB6
PA04
PA11
PA05
Boot Jumper
PA09
PA06
2044-2X05G00RA C49569855
PA12
PA07

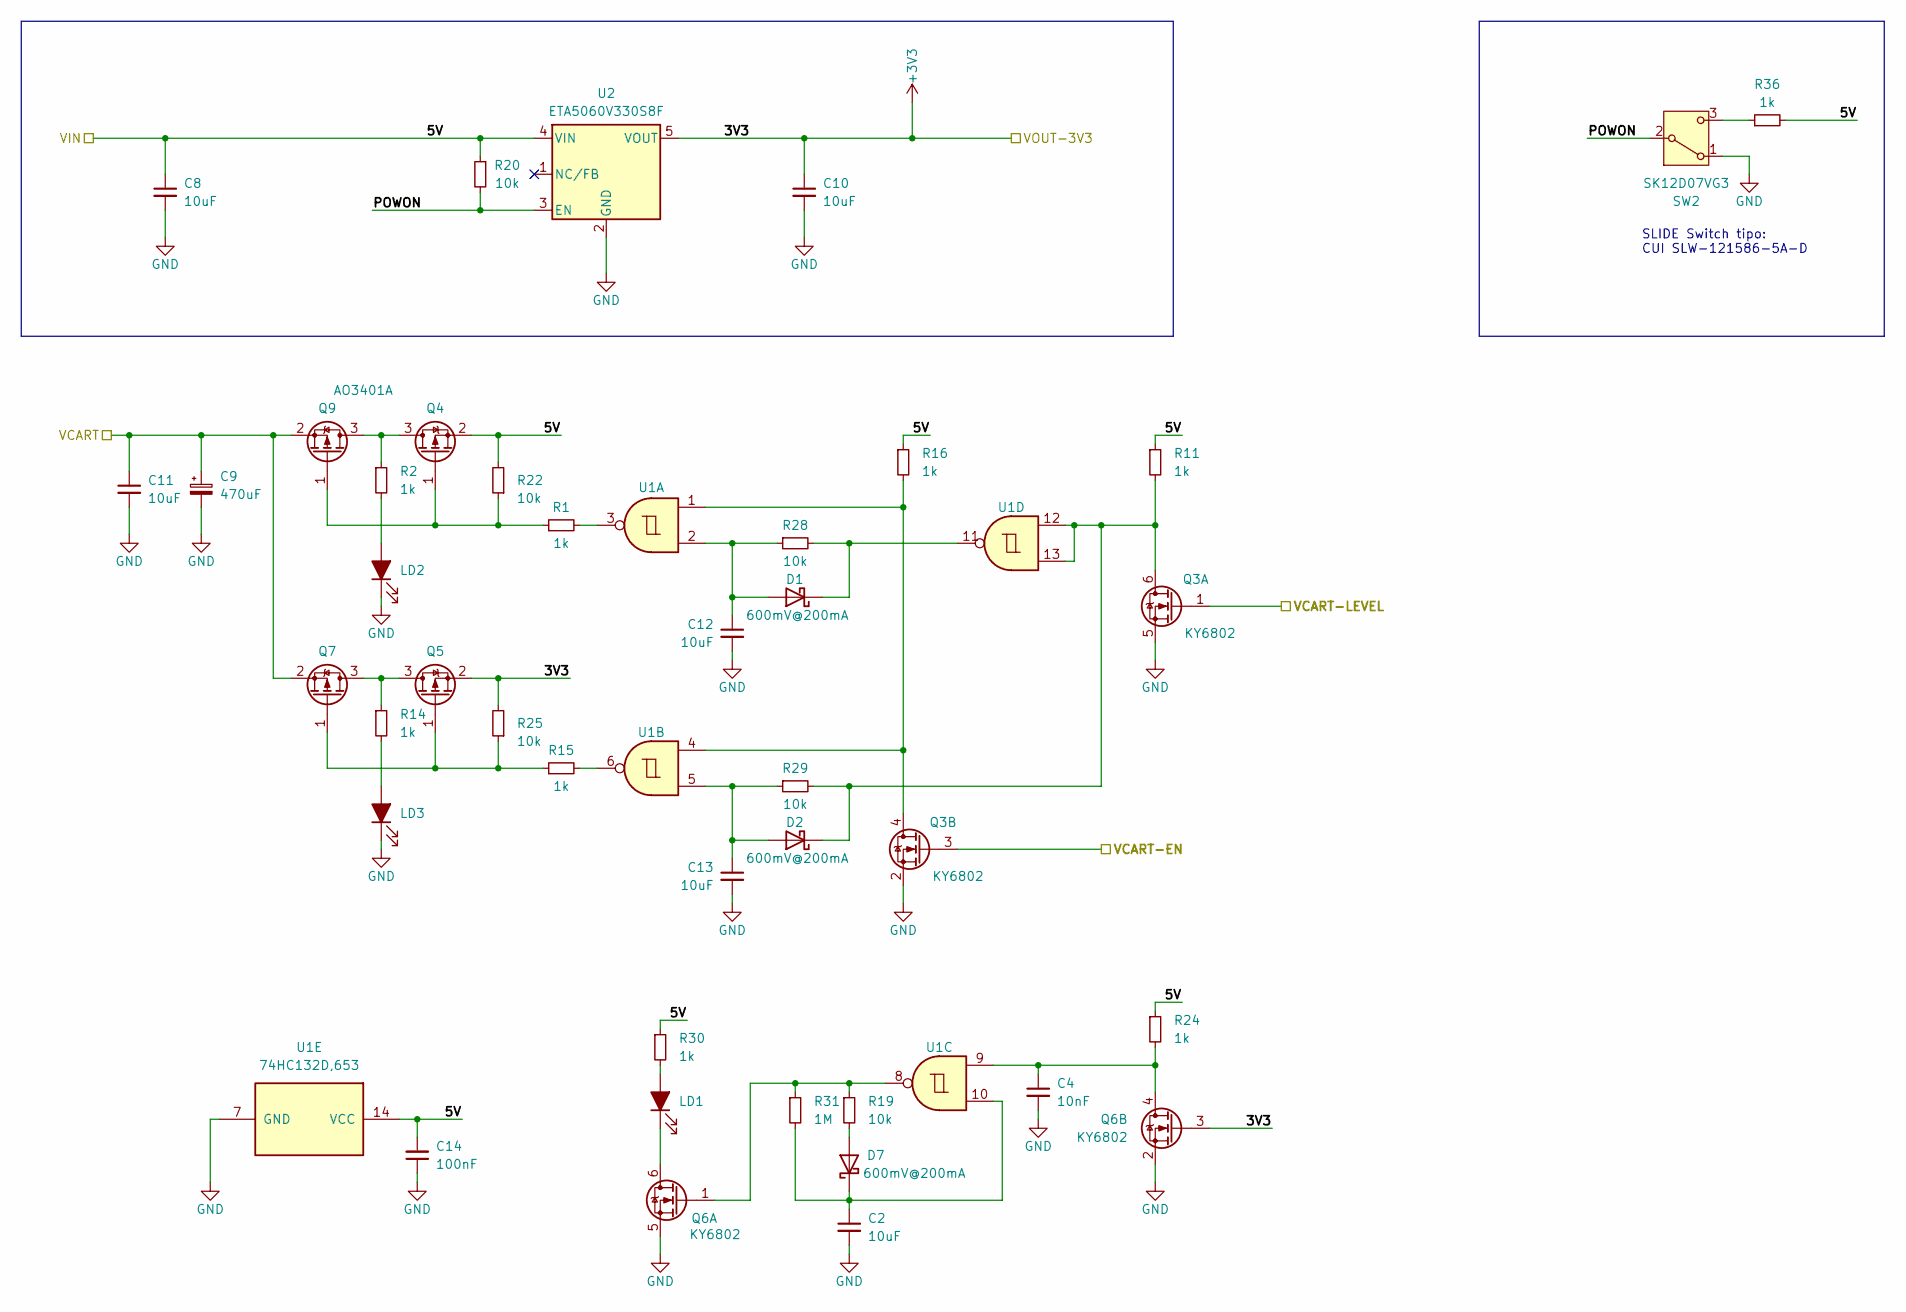
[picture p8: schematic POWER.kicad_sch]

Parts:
C2, C8, C10, C11, C12, C13: 10uF; C_1206_3216Metric_Pad1.33x1.80mm_HandSolder
C4: 10nF; C_0805_2012Metric_Pad1.18x1.45mm_HandSolder
C9: 470uF; CP_Elec_6.3x7.7
C14: 100nF; C_0805_2012Metric_Pad1.18x1.45mm_HandSolder
D1, D2, D7: 600mV@200mA; D_SOD-123F
LD1, LD2, LD3: LED_Filled; LED_0805_2012Metric_Pad1.15x1.40mm_HandSolder
Q3, Q6: KY6802; SOT-23-6_Handsoldering
Q4, Q5, Q7, Q9: AO3401; SOT-23
R1, R2, R11, R14, R15, R16, R24, R30, R36: 1k; R_0805_2012Metric_Pad1.20x1.40mm_HandSolder
R19, R20, R22, R25, R28, R29: 10k; R_0805_2012Metric_Pad1.20x1.40mm_HandSolder
R31: 1M; R_0805_2012Metric_Pad1.20x1.40mm_HandSolder
SW2: SK12D07VG3; SW_Slide_SPDT_Angled_CK_OS102011MA1Q
U1: 74HC132D,653; SOIC-14_3.9x8.7mm_P1.27mm
U2: ETA5060V330S8F; SOT-89-5

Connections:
5V-USB: C8.1, C14.2, Q4.2 (S), R11.1, R16.1, R20.1, R22.2, R24.1, R30.1, R36.2, U1.14 (VCC), U2.4 (VIN); also elsewhere on the board
+3V3: C10.1, Q5.2 (S), Q6.3 (G), R25.2, U2.5 (VOUT); also elsewhere on the board
/MCU/MCU_VCART_EN: Q3.3 (G); also elsewhere on the board
/MCU/MCU_VCART_LV: Q3.1 (G); also elsewhere on the board
/POWER1/POWON: R20.2, SW2.2 (B), U2.3 (EN)
GND: C2.2, C4.2, C8.2, C9.2, C10.2, C11.2, C12.2, C13.2, C14.1, LD2.1 (K), LD3.1 (K), Q3.2 (S), Q3.5 (S), Q6.2 (S), Q6.5 (S), SW2.1 (A), U1.7 (GND), U2.2 (GND); also elsewhere on the board
unnamed: C12.1, D1.2 (A), R28.1, U1.2
unnamed: D1.1 (K), R28.2, U1.11
unnamed: C13.1, D2.2 (A), R29.1, U1.5
unnamed: D2.1 (K), Q3.6 (D), R11.2, R29.2, U1.12, U1.13
unnamed: D7.2 (A), R19.2
unnamed: C2.1, D7.1 (K), R31.2, U1.10
unnamed: LD1.2 (A), R30.2
unnamed: LD1.1 (K), Q6.6 (D)
unnamed: LD2.2 (A), R2.2
unnamed: LD3.2 (A), R14.2
unnamed: Q3.4 (D), R16.2, U1.1, U1.4
unnamed: Q4.3 (D), Q9.3 (D), R2.1
unnamed: Q4.1 (G), Q9.1 (G), R1.1, R22.1
unnamed: Q5.3 (D), Q7.3 (D), R14.1
unnamed: Q5.1 (G), Q7.1 (G), R15.1, R25.1
unnamed: Q6.1 (G), R19.1, R31.1, U1.8
unnamed: C4.1, Q6.4 (D), R24.2, U1.9
unnamed: R1.2, U1.3
unnamed: R15.2, U1.6
unnamed: R36.1, SW2.3 (C)
VDD-CART: C9.1, C11.1, Q7.2 (S), Q9.2 (S); also elsewhere on the board

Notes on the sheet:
SLIDE Switch tipo: CUI SLW-121586-5A-D

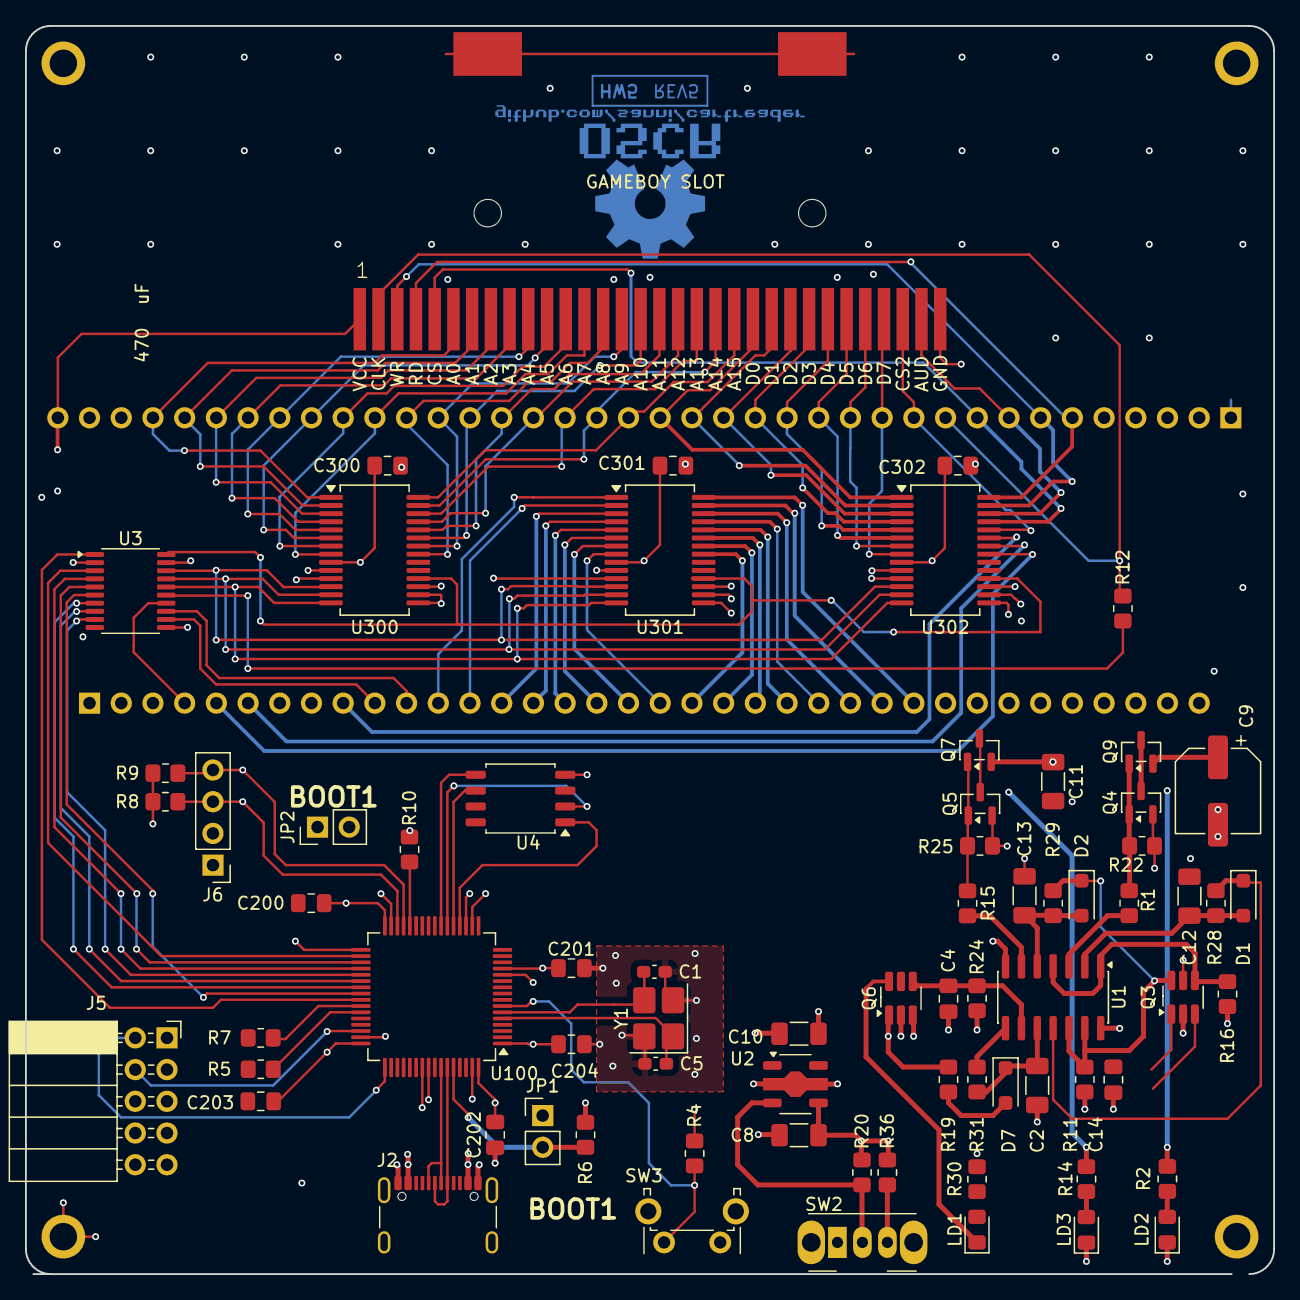
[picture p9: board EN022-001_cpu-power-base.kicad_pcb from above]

Board: 4 copper layers, 100.0 x 100.0 mm, 78 parts (0 on the bottom side), 113 nets.

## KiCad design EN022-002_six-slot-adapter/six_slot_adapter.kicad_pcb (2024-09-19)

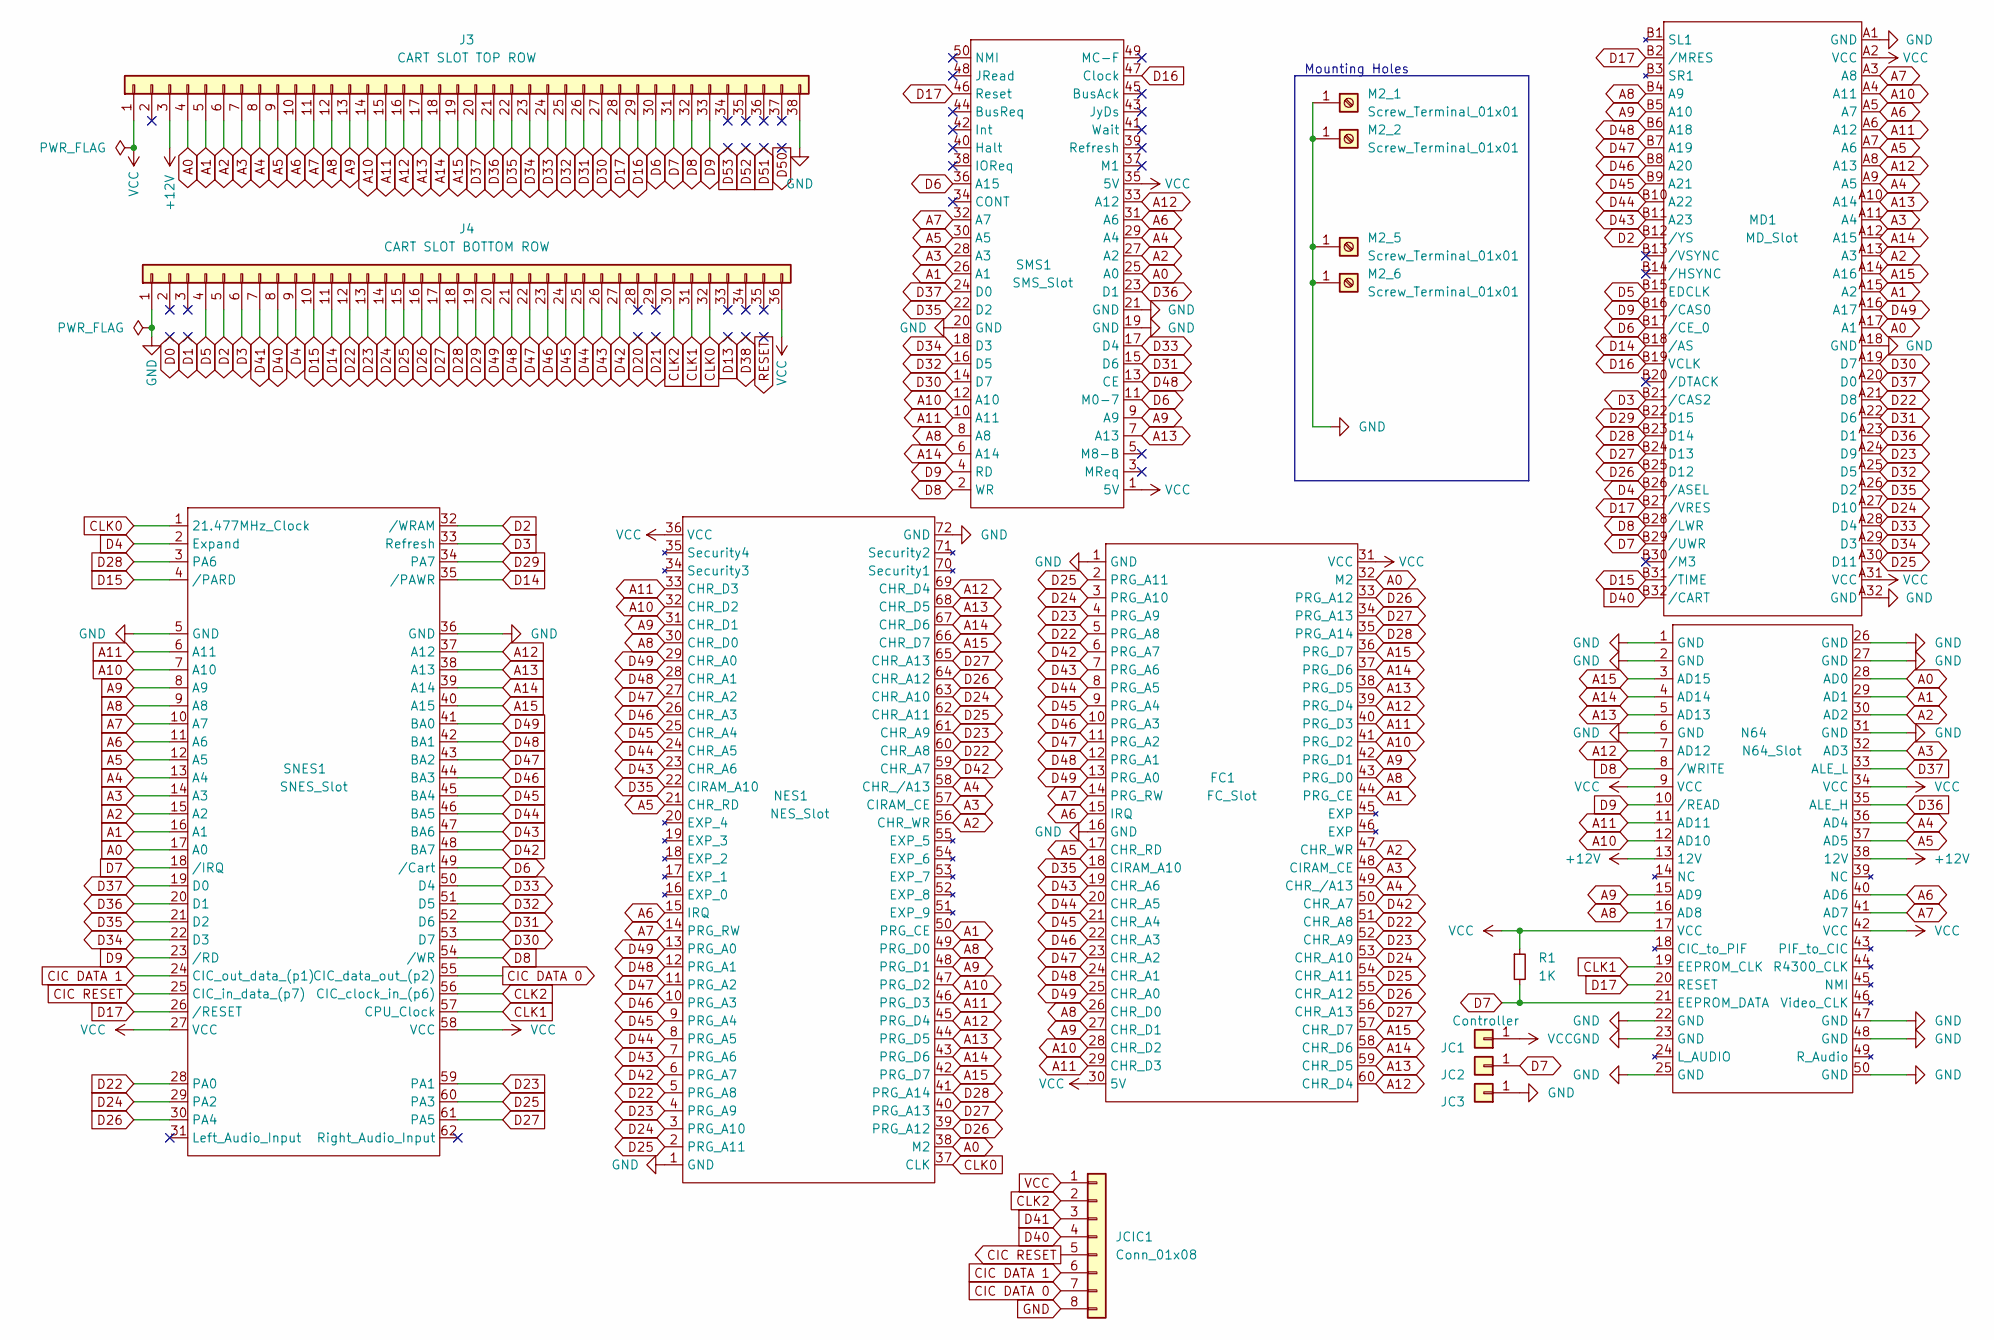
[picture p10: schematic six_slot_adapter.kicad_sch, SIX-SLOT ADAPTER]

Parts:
FC1: FC_Slot
J3: CART SLOT TOP ROW; PinSocket_1x38_P2.54mm_Vertical
J4: CART SLOT BOTTOM ROW; PinSocket_1x36_P2.54mm_Vertical
JC1: Controller; PinHeader_1x01_P2.54mm_Vertical
JC2, JC3: Conn_01x01; PinHeader_1x01_P2.54mm_Vertical
JCIC1: Conn_01x08; PinHeader_1x08_P2.54mm_Vertical
M2_1, M2_2, M2_5, M2_6: Screw_Terminal_01x01; MountingHole_2.2mm_M2_ISO7380_Pad
MD1: MD_Slot
N64: N64_Slot; N64 Slot
NES1: NES_Slot
R1: 1K; R_Axial_DIN0207_L6.3mm_D2.5mm_P10.16mm_Horizontal
SMS1: SMS_Slot
SNES1: SNES_Slot; SNES Slot

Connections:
+12V: J3.3, N64.13 (12V), N64.38 (12V)
A0: FC1.32 (M2), J3.4, MD1.A17 (A1), N64.28 (AD0), NES1.38 (M2), SMS1.25 (A0), SNES1.17 (A0)
A1: FC1.44 (PRG_CE), J3.5, MD1.A15 (A2), N64.29 (AD1), NES1.50 (PRG_CE), SMS1.26 (A1), SNES1.16 (A1)
A2: FC1.47 (CHR_WR), J3.6, MD1.A13 (A3), N64.30 (AD2), NES1.56 (CHR_WR), SMS1.27 (A2), SNES1.15 (A2)
A3: FC1.48 (CIRAM_CE), J3.7, MD1.A11 (A4), N64.32 (AD3), NES1.57 (CIRAM_CE), SMS1.28 (A3), SNES1.14 (A3)
A4: FC1.49 (CHR_/A13), J3.8, MD1.A9 (A5), N64.36 (AD4), NES1.58 (CHR_/A13), SMS1.29 (A4), SNES1.13 (A4)
A5: FC1.17 (CHR_RD), J3.9, MD1.A7 (A6), N64.37 (AD5), NES1.21 (CHR_RD), SMS1.30 (A5), SNES1.12 (A5)
A6: FC1.15 (IRQ), J3.10, MD1.A5 (A7), N64.40 (AD6), NES1.15 (IRQ), SMS1.31 (A6), SNES1.11 (A6)
A7: FC1.14 (PRG_RW), J3.11, MD1.A3 (A8), N64.41 (AD7), NES1.14 (PRG_RW), SMS1.32 (A7), SNES1.10 (A7)
A8: FC1.26 (CHR_D0), FC1.43 (PRG_D0), J3.12, MD1.B4 (A9), N64.16 (AD8), NES1.30 (CHR_D0), NES1.49 (PRG_D0), SMS1.8 (A8), SNES1.9 (A8)
A9: FC1.27 (CHR_D1), FC1.42 (PRG_D1), J3.13, MD1.B5 (A10), N64.15 (AD9), NES1.31 (CHR_D1), NES1.48 (PRG_D1), SMS1.9 (A9), SNES1.8 (A9)
A10: FC1.28 (CHR_D2), FC1.41 (PRG_D2), J3.14, MD1.A4 (A11), N64.12 (AD10), NES1.32 (CHR_D2), NES1.47 (PRG_D2), SMS1.12 (A10), SNES1.7 (A10)
A11: FC1.29 (CHR_D3), FC1.40 (PRG_D3), J3.15, MD1.A6 (A12), N64.11 (AD11), NES1.33 (CHR_D3), NES1.46 (PRG_D3), SMS1.10 (A11), SNES1.6 (A11)
A12: FC1.39 (PRG_D4), FC1.60 (CHR_D4), J3.16, MD1.A8 (A13), N64.7 (AD12), NES1.45 (PRG_D4), NES1.69 (CHR_D4), SMS1.33 (A12), SNES1.37 (A12)
A13: FC1.38 (PRG_D5), FC1.59 (CHR_D5), J3.17, MD1.A10 (A14), N64.5 (AD13), NES1.44 (PRG_D5), NES1.68 (CHR_D5), SMS1.7 (A13), SNES1.38 (A13)
A14: FC1.37 (PRG_D6), FC1.58 (CHR_D6), J3.18, MD1.A12 (A15), N64.4 (AD14), NES1.43 (PRG_D6), NES1.67 (CHR_D6), SMS1.6 (A14), SNES1.39 (A14)
A15: FC1.36 (PRG_D7), FC1.57 (CHR_D7), J3.19, MD1.A14 (A16), N64.3 (AD15), NES1.42 (PRG_D7), NES1.66 (CHR_D7), SNES1.40 (A15)
CIC DATA 0: JCIC1.7, SNES1.55 (CIC_data_out_(p2))
CIC DATA 1: JCIC1.6, SNES1.24 (CIC_out_data_(p1))
CIC RESET: JCIC1.5, SNES1.25 (CIC_in_data_(p7))
CLK0: J4.32, NES1.37 (CLK), SNES1.1 (21.477MHz_Clock)
CLK1: J4.31, N64.19 (EEPROM_CLK), SNES1.57 (CPU_Clock)
CLK2: J4.30, JCIC1.2, SNES1.56 (CIC_clock_in_(p6))
D2: J4.5, MD1.B12 (/YS), SNES1.32 (/WRAM)
D3: J4.6, MD1.B21 (/CAS2), SNES1.33 (Refresh)
D4: J4.9, MD1.B26 (/ASEL), SNES1.2 (Expand)
D5: J4.4, MD1.B15 (EDCLK)
D6: J3.30, MD1.B17 (/CE_0), SMS1.11 (M0-7), SMS1.36 (A15), SNES1.49 (/Cart)
D7: J3.31, JC2.1, MD1.B29 (/UWR), N64.21 (EEPROM_DATA), R1.2, SNES1.18 (/IRQ)
D8: J3.32, MD1.B28 (/LWR), N64.8 (/WRITE), SMS1.2 (WR), SNES1.54 (/WR)
D9: J3.33, MD1.B16 (/CAS0), N64.10 (/READ), SMS1.4 (RD), SNES1.23 (/RD)
D14: J4.11, MD1.B18 (/AS), SNES1.35 (/PAWR)
D15: J4.10, MD1.B31 (/TIME), SNES1.4 (/PARD)
D16: J3.29, MD1.B19 (VCLK), SMS1.47 (Clock)
D17: J3.28, MD1.B2 (/MRES), MD1.B27 (/VRES), N64.20 (RESET), SMS1.46 (Reset), SNES1.26 (/RESET)
D22: FC1.5 (PRG_A8), FC1.51 (CHR_A8), J4.12, MD1.A21 (D8), NES1.5 (PRG_A8), NES1.60 (CHR_A8), SNES1.28 (PA0)
D23: FC1.4 (PRG_A9), FC1.52 (CHR_A9), J4.13, MD1.A24 (D9), NES1.4 (PRG_A9), NES1.61 (CHR_A9), SNES1.59 (PA1)
D24: FC1.3 (PRG_A10), FC1.53 (CHR_A10), J4.14, MD1.A27 (D10), NES1.3 (PRG_A10), NES1.63 (CHR_A10), SNES1.29 (PA2)
D25: FC1.2 (PRG_A11), FC1.54 (CHR_A11), J4.15, MD1.A30 (D11), NES1.2 (PRG_A11), NES1.62 (CHR_A11), SNES1.60 (PA3)
D26: FC1.33 (PRG_A12), FC1.55 (CHR_A12), J4.16, MD1.B25 (D12), NES1.39 (PRG_A12), NES1.64 (CHR_A12), SNES1.30 (PA4)
D27: FC1.34 (PRG_A13), FC1.56 (CHR_A13), J4.17, MD1.B24 (D13), NES1.40 (PRG_A13), NES1.65 (CHR_A13), SNES1.61 (PA5)
D28: FC1.35 (PRG_A14), J4.18, MD1.B23 (D14), NES1.41 (PRG_A14), SNES1.3 (PA6)
D29: J4.19, MD1.B22 (D15), SNES1.34 (PA7)
D30: J3.27, MD1.A19 (D7), SMS1.14 (D7), SNES1.53 (D7)
D31: J3.26, MD1.A22 (D6), SMS1.15 (D6), SNES1.52 (D6)
D32: J3.25, MD1.A25 (D5), SMS1.16 (D5), SNES1.51 (D5)
D33: J3.24, MD1.A28 (D4), SMS1.17 (D4), SNES1.50 (D4)
D34: J3.23, MD1.A29 (D3), SMS1.18 (D3), SNES1.22 (D3)
D35: FC1.18 (CIRAM_A10), J3.22, MD1.A26 (D2), NES1.22 (CIRAM_A10), SMS1.22 (D2), SNES1.21 (D2)
D36: J3.21, MD1.A23 (D1), N64.35 (ALE_H), SMS1.23 (D1), SNES1.20 (D1)
D37: J3.20, MD1.A20 (D0), N64.33 (ALE_L), SMS1.24 (D0), SNES1.19 (D0)
D40: J4.8, JCIC1.4, MD1.B32 (/CART)
D41: J4.7, JCIC1.3
D42: FC1.6 (PRG_A7), FC1.50 (CHR_A7), J4.27, NES1.6 (PRG_A7), NES1.59 (CHR_A7), SNES1.48 (BA7)
D43: FC1.7 (PRG_A6), FC1.19 (CHR_A6), J4.26, MD1.B11 (A23), NES1.7 (PRG_A6), NES1.23 (CHR_A6), SNES1.47 (BA6)
D44: FC1.8 (PRG_A5), FC1.20 (CHR_A5), J4.25, MD1.B10 (A22), NES1.8 (PRG_A5), NES1.24 (CHR_A5), SNES1.46 (BA5)
D45: FC1.9 (PRG_A4), FC1.21 (CHR_A4), J4.24, MD1.B9 (A21), NES1.9 (PRG_A4), NES1.25 (CHR_A4), SNES1.45 (BA4)
D46: FC1.10 (PRG_A3), FC1.22 (CHR_A3), J4.23, MD1.B8 (A20), NES1.10 (PRG_A3), NES1.26 (CHR_A3), SNES1.44 (BA3)
D47: FC1.11 (PRG_A2), FC1.23 (CHR_A2), J4.22, MD1.B7 (A19), NES1.11 (PRG_A2), NES1.27 (CHR_A2), SNES1.43 (BA2)
D48: FC1.12 (PRG_A1), FC1.24 (CHR_A1), J4.21, MD1.B6 (A18), NES1.12 (PRG_A1), NES1.28 (CHR_A1), SMS1.13 (CE), SNES1.42 (BA1)
D49: FC1.13 (PRG_A0), FC1.25 (CHR_A0), J4.20, MD1.A16 (A17), NES1.13 (PRG_A0), NES1.29 (CHR_A0), SNES1.41 (BA0)
GND: FC1.1 (GND), FC1.16 (GND), J3.38, J4.1, JC3.1, JCIC1.8, M2_1.1, M2_2.1, M2_5.1, M2_6.1, MD1.A1 (GND), MD1.A18 (GND), MD1.A32 (GND), N64.1 (GND), N64.2 (GND), N64.6 (GND), N64.22 (GND), N64.23 (GND), N64.25 (GND), N64.26 (GND), N64.27 (GND), N64.31 (GND), N64.47 (GND), N64.48 (GND), N64.50 (GND), NES1.1 (GND), NES1.72 (GND), SMS1.19 (GND), SMS1.20 (GND), SMS1.21 (GND), SNES1.5 (GND), SNES1.36 (GND)
VCC: FC1.30 (5V), FC1.31 (VCC), J3.1, J4.36, JC1.1, JCIC1.1, MD1.A2 (VCC), MD1.A31 (VCC), N64.9 (VCC), N64.17 (VCC), N64.34 (VCC), N64.42 (VCC), NES1.36 (VCC), R1.1, SMS1.1 (5V), SMS1.35 (5V), SNES1.27 (VCC), SNES1.58 (VCC)

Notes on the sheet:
Mounting Holes

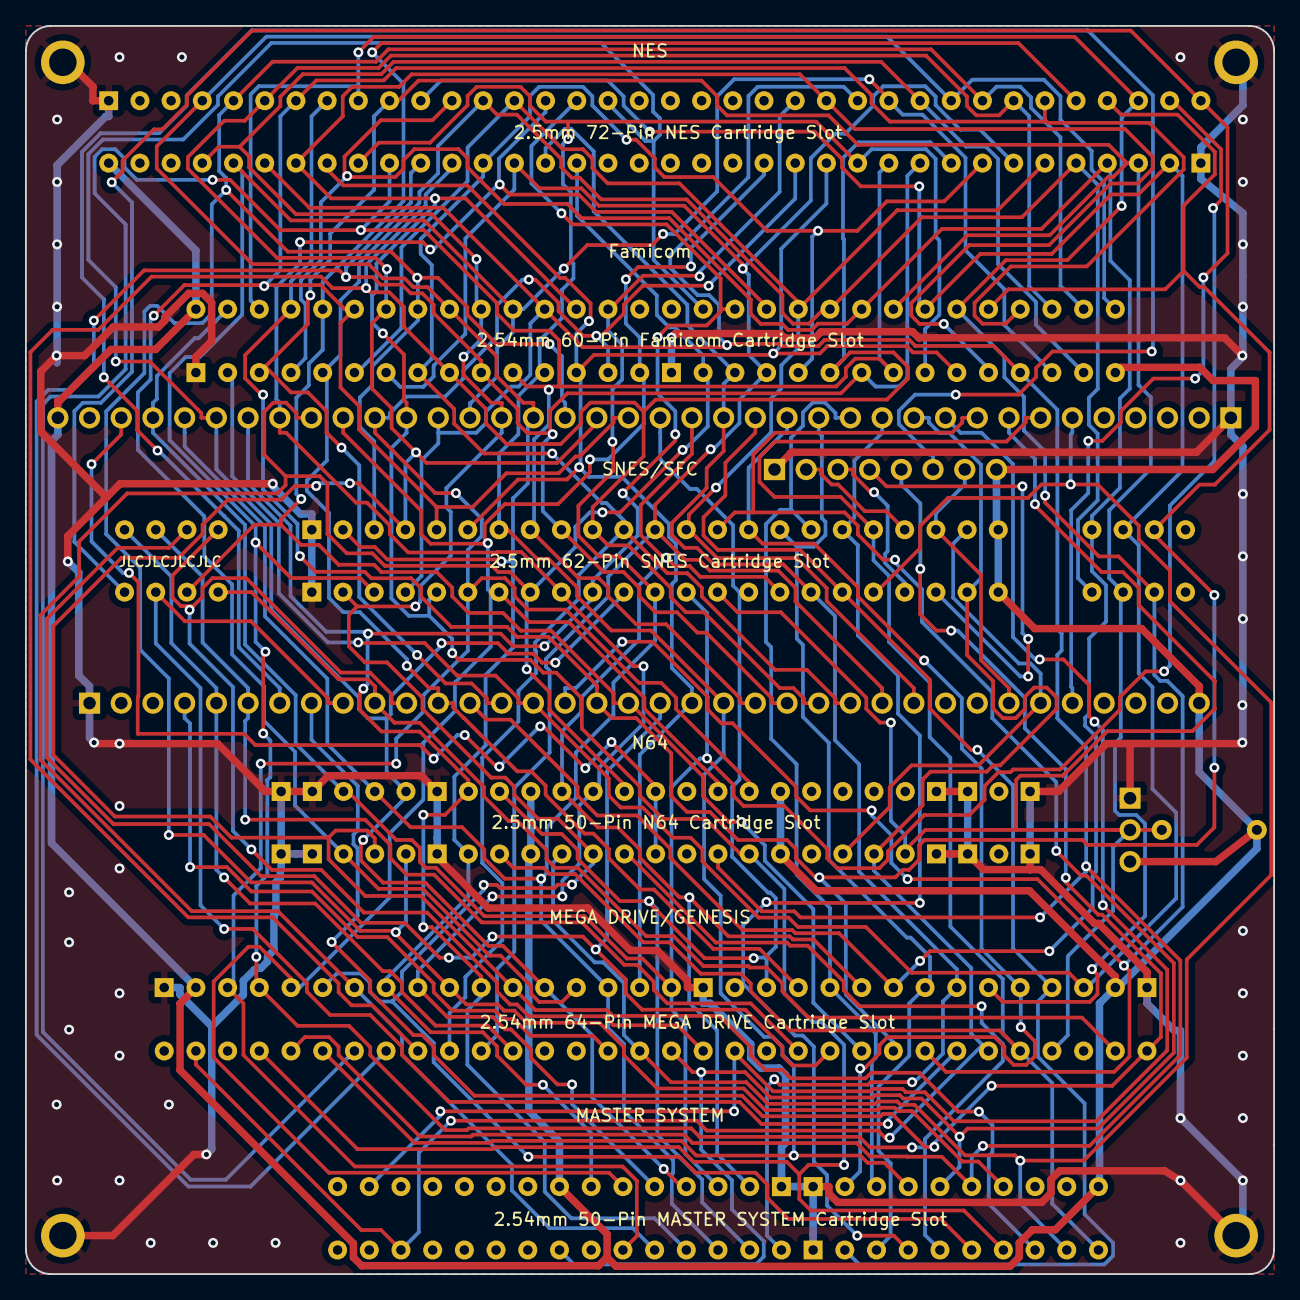
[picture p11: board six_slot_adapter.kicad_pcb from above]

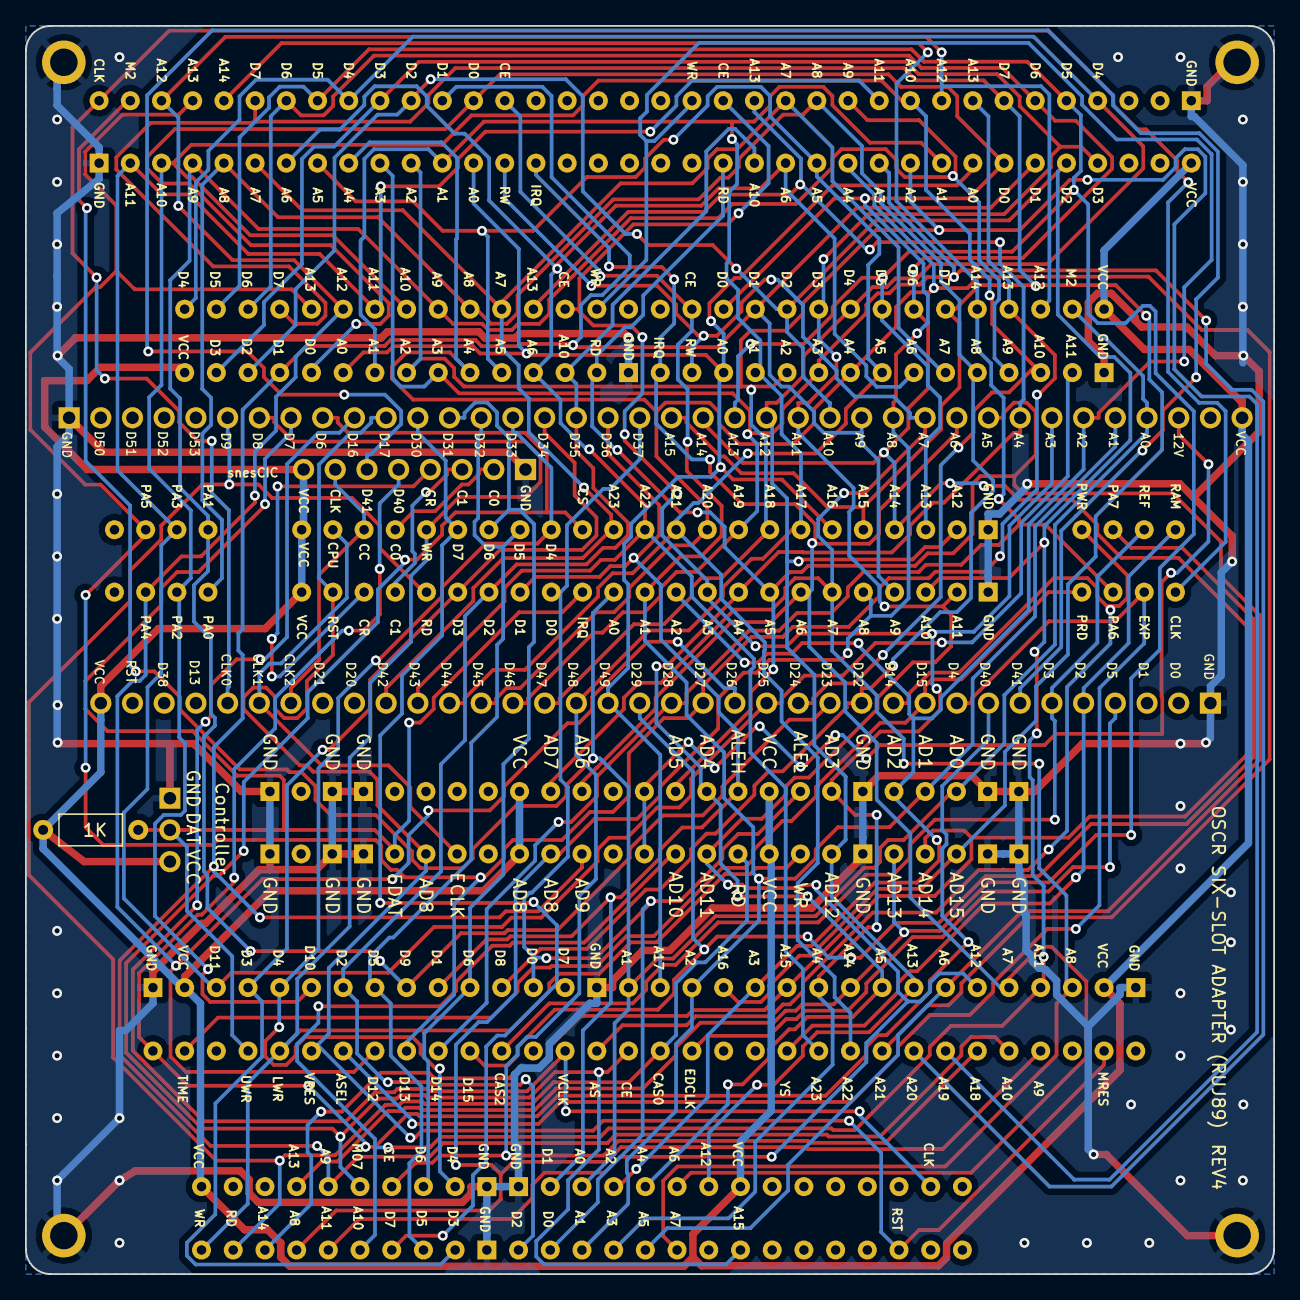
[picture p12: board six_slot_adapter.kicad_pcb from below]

Board: 2 copper layers, 100.0 x 100.0 mm, 17 parts (6 on the bottom side), 63 nets.

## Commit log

2024-09-19 OSCR footprints
2024-09-19 CPU board project
    [main_pcb_hw5.kicad_pcb, main_pcb_hw5.kicad_sch]
2024-09-19 slot adapter project
    [six_slot_adapter.kicad_pcb, six_slot_adapter.kicad_sch, vselect.kicad_sch]
2024-09-19 project rename
    [EN022-001_cpu-power-base.kicad_pcb, EN022-001_cpu-power-base.kicad_sch]
2024-09-19 applied page layout
    [EN022-001_cpu-power-base.kicad_pcb, EN022-001_cpu-power-base.kicad_sch, vselect.kicad_sch]
2024-09-19 check holeposition
2024-09-19 mountin holes position
    [EN022-001_cpu-power-base.kicad_pcb, EN022-001_cpu-power-base.kicad_sch]
2024-09-19 Removed atmega board connector
    [EN022-001_cpu-power-base.kicad_pcb, EN022-001_cpu-power-base.kicad_sch]
2024-09-19 update GBA slot ground pin name to SH1/2
2024-09-19 added 3D model to GBA slot connector
2024-09-19 updateted GBA slot
    [EN022-001_cpu-power-base.kicad_pcb, EN022-001_cpu-power-base.kicad_sch]
2024-09-19 pcb traces cleanup
    [EN022-001_cpu-power-base.kicad_pcb]
2024-09-22 GBA slot technical ref
2024-09-22 cpu pinout and bus references
    [pinout.csv]
2026-01-24 added power section
    [POWER.kicad_sch]
2026-01-25 first cimplete version of CPU POWER BASE
    [BASE.kicad_sch, EN022-001_cpu-power-base.kicad_pcb, EN022-001_cpu-power-base.kicad_sch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]
2026-01-25 moved GBA connector step file to footprint folder
    [GBA_CartConnector.step]
